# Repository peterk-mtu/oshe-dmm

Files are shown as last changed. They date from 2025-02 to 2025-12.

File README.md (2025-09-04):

# oshe-dmm
open source hardware enterprise digital multimeter project

# Photo of our proposed design
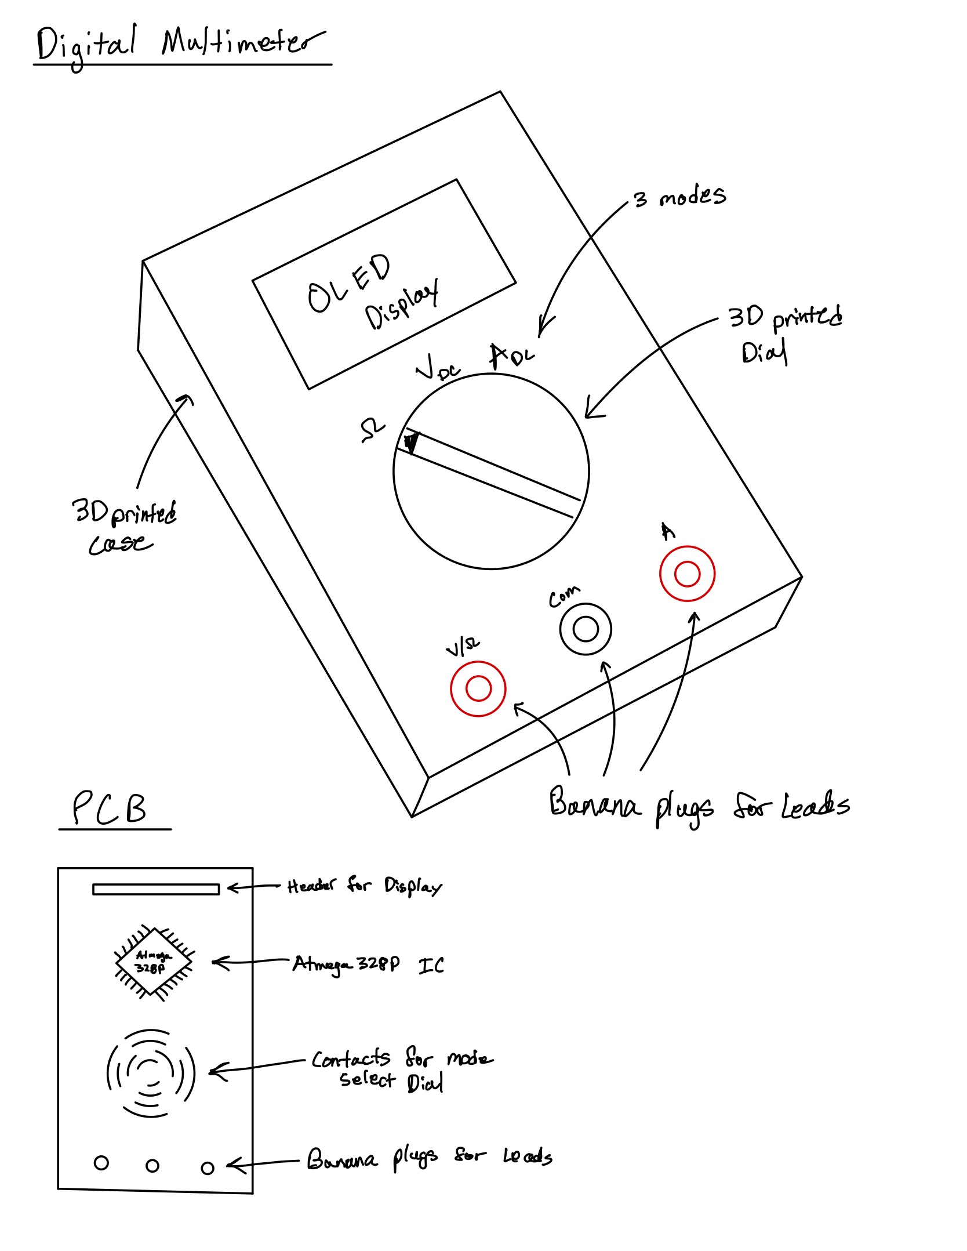
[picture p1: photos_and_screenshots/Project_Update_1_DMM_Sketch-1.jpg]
A rough sketch of our proposed design


# Screenshot of the start to our PCB design
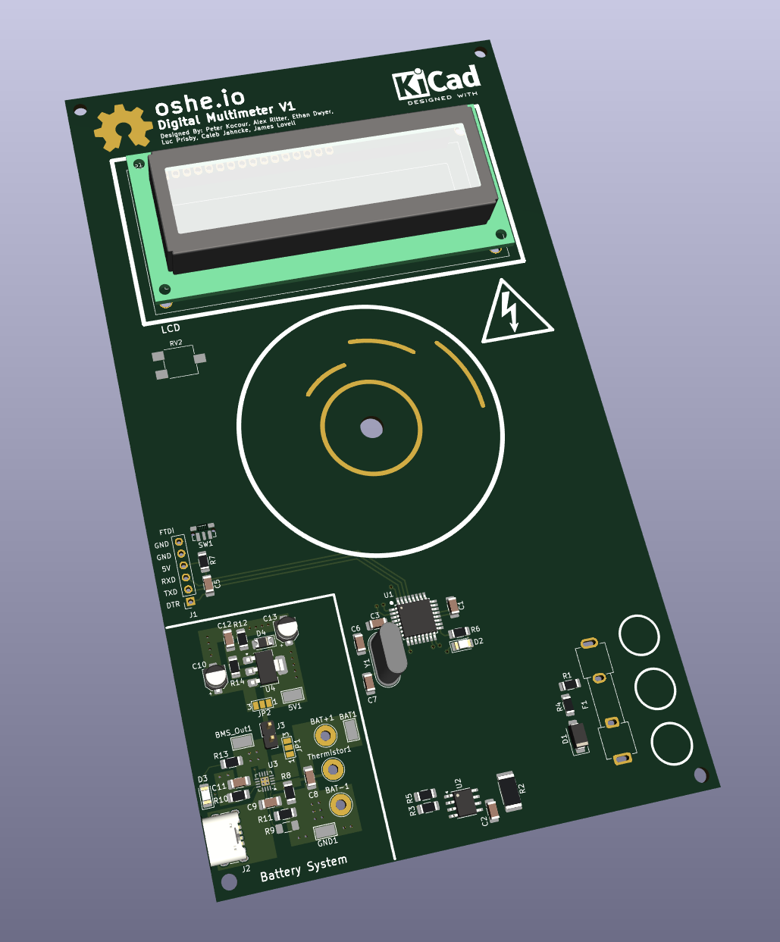
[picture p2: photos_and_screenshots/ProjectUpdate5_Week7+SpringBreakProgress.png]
A screenshot of our inital PCB work


# Screenshot of the Final PCB design
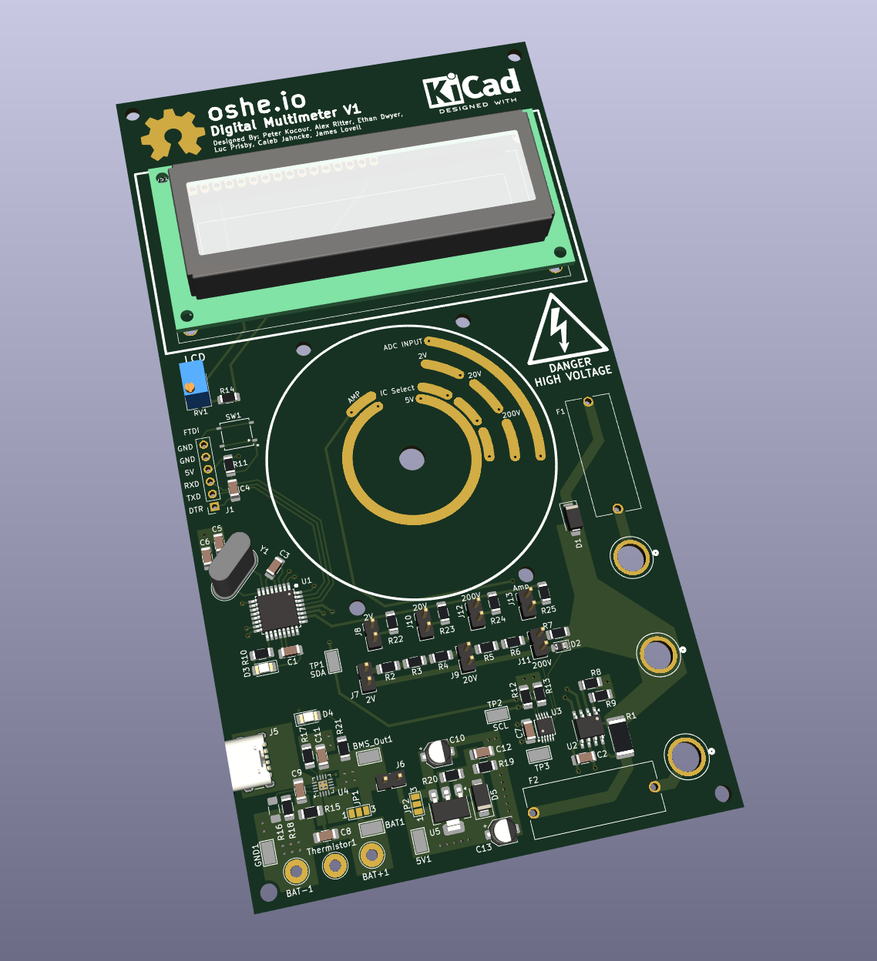
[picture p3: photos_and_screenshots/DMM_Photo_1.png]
A screenshot of our Final PCB Design


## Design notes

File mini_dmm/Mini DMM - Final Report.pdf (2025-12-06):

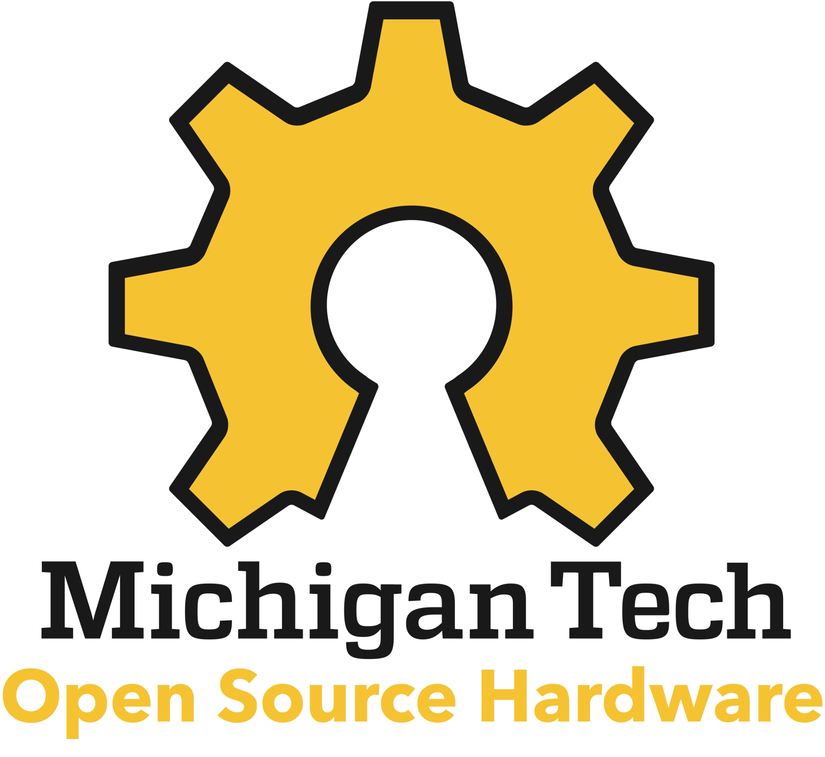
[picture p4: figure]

# Mini Digital Multimeter Project

## Fall 2025 Report

### Project Team: Peter Kocour Ian Ranstadler Nathan Campbell

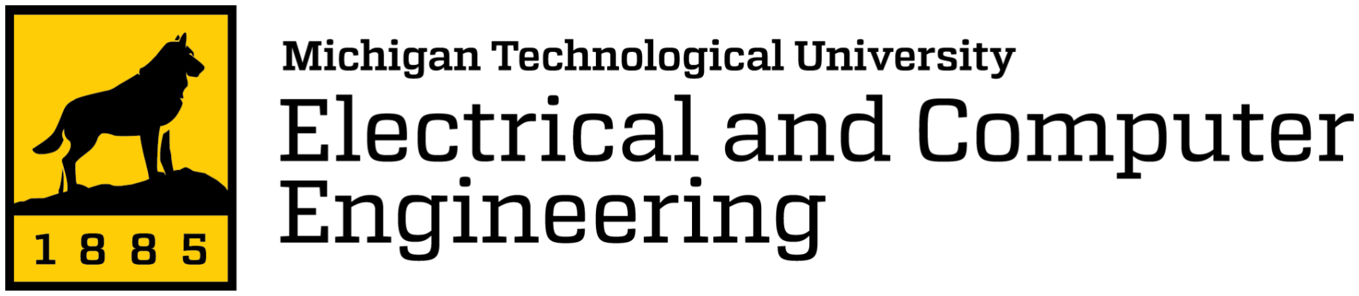
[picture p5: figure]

Mini Digital Multimeter Project Report | Fall 2025

### Table of Contents

### 1. Executive Summary

The Mini Digital Multimeter Project presents a compact measurement device, about the size of a credit card, which is capable of capturing DC voltage measurements of up to 30 volts and DC current measurements of up to 1 amp. It’s designed with affordability and mass production in mind, maintaining a bill of materials cost of roughly $10 per unit at a scale of 100 units.

Core Technology
The Digital Multimeter utilizes the ATmega328P microcontroller, common on arduino platforms, supplemented by a four circuit op-amp, a charge pump, a display driver, and a 4 digit display. The four circuit op-amp provides a buffer for the inputs of the ATmega internal ADC for voltage measurements and provides amplification for the current measurements. The op-amp is provided with both a positive 3.3 volt supply via the battery and a negative 3.3 volt supply via the charge pump. The measured voltages and currents are then displayed through the display driver and onto the 4 digit display.

Innovations
Several key innovations were integrated in the mini digital multimeter, from a unique display and display driver combo to a single op-amp floating shunt resistor circuit measurement circuit, which pushed the limits of accuracy while maintaining a low overall bill of material cost. The display driver and 4 digit display proved to be the most challenging, requiring a deep dive into the display driver datasheet and the C++ code to determine how to get the correct segments to turn on and off on the display based on a collected measurement. Another innovation was the addition of a charge pump to provide the required negative 3.3 volts for the supply rail of the op-amp with the addition of a few capacitors. For current measurement, it was discovered that the change in voltage drop across a small shunt resistor was too small for the internal ADC to see, thus requiring some sort of amplification to make it easier to identify changes in voltages and thus changes in currents.

Challenges and Solutions
Our greatest challenge with the project stemmed from the display and display driver IC. One critical part of the project was keeping costs low. The display on the previous design was not only physically bulky but pretty pricey for our goal of a small, low cost device. Moving away from the LCD to a cheaper alternative proved limiting and challenging. Most displays were not cheap, often in the range of $2 to $5, much more than we would like to spend. As a solution, we found the LCD-S401M16KR by Lumex which was at most $1.67 at low quantities, but more importantly, the price dropped to $0.8991 when ordering a quantity of 100. While this initially solved our first problem, it created a second, driving the display that wants an AC voltage signal. One potential solution was using a PWM signal from the microcontroller pins to see if that would be enough to turn on and off the display. During testing this solution almost worked, however, it took up all of the GPIO pins, saving nothing for the rest of the devices, like LEDs, switches, etc, we needed to use. This ultimately led to the use of the BU91796FS-ME2 display driver IC. This device could be communicated with over I2C, would handle all of the AC signal,

1/4 duty, 1/3 bias, requirements of the display and only cost $1.1022, putting our total cost at just around $2 being one of the cheapest options. Pawning off the control of the display to this driver frees up many of the GPIO pins on the microcontroller while also handling all of the challenges with driving the display. That being said, this solution still introduced another problem, finding the right I2C commands to turn on and off the current segments on the display when we need or want to. Programming the correct commands was a challenge that didn’t get solved at the end of the semester. While some of the segments turn on when commanded displaying the numbers 1, 4, 0, 5, and a few others correctly, not every segment turns on when needed, preventing every number from being displayed correctly. With some more time spent in the datasheet for the display driver and the I2C commands, the correct commands could eventually be determined.

Impact
The Open Source MINI Digital Multimeter offers a hands-on give-away item to future MTU students or others interested in electronics. This device will give its users a hands-on education of electronics, promoting technical development at a fraction of the cost of a commercial multimeter. By open-sourcing hardware and software, this project encourages students, makers, and educators to innovate, customize, and better understand electronics and electrical tools.

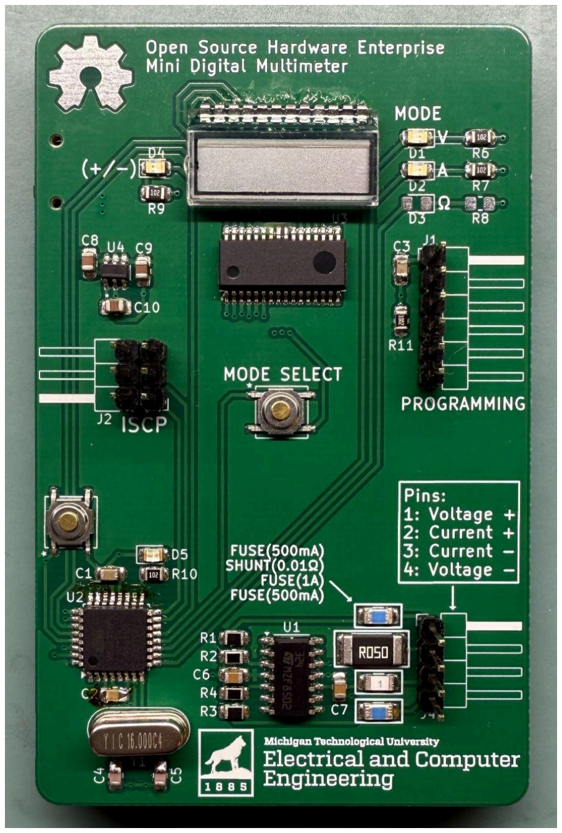
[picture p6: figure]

Figure 1: Mini DMM Version 1 Product Image

### 2. Project Description

The Mini Digital Multimeter Project presents a compact measurement device, about the size of a credit card, which is capable of capturing DC voltage measurements of up to 30 volts, DC current measurements of up to 1 amp, and resistance measurements up to 100,000 ohms. Designed with affordability and mass production in mind, the device will maintain a bill of materials cost of roughly $10 per unit at a scale of 100 units and prioritize surface mount components while minimizing through hole components where possible. Switching between measurement modes will be easy and intuitive, with a clear mode selection button and indicators to guide users to their desired measurement type. This device will also employ numerous safety features such as fuses, graphical warnings and an enclosure to protect users and ensure safe operation.

### 3. Methodology

### 3.1 Voltage Measurement

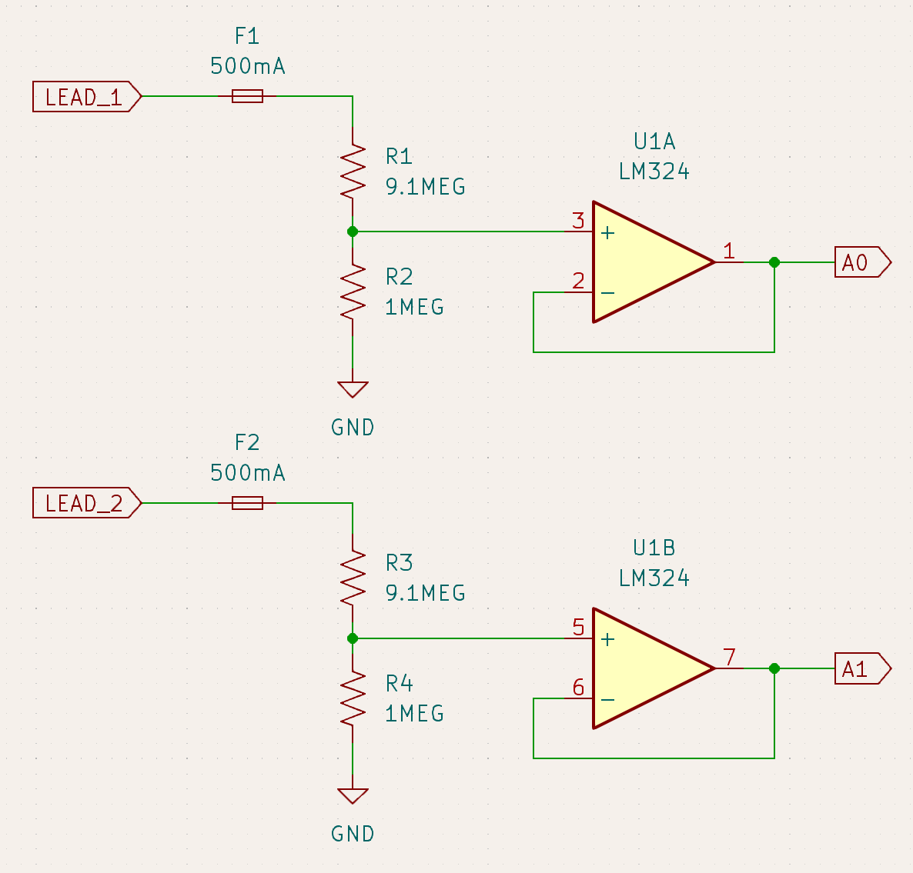
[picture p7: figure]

Figure 2: Voltage measurement schematic

Voltage measurement was one of the most important design aspects of our project. When laid out in our project specifications, we ultimately decided that we wanted the voltage to be measured in DC between ± 30 V and we wanted that measured value to be within ±10% of any commercially available device that it was put up against. Our final design for voltage measurement can be seen above in Figure 2, which was composed of two separate circuits. Initially, we considered using a processor that was capable of taking differential measurements as we thought this would be the way that our voltage measurements were taken. However, we found a different method where that differential measurement requirement was not needed. This allowed us to switch our processor to the ATmega328p which was cheaper, programmable in the Arduino IDE, and had more open pins which was helpful as we ran out while using the STM32F303. The circuit itself makes use of two separate voltage dividers with a known ratio, 10.1:1. Using this ratio and some simple math, we were able to take two different voltage measurements between our probes and subtract one from the other. The voltage divider also allowed us to get our input voltage into our Op-amps to be ±3V, as we only had a ±3V supply rail available to run our components. The buffer op-amps added before the ADC input are meant to prevent input impedance from our test leads, and thus making our measurements more accurate. For safety reasons, we also added 500 mA fuses just after leads to prevent the ADC from burning up should an unexpected current be placed through the leads. These components were ultimately decided to be simple SMD components due to their price, though they can be replaced by the right person.

### 3.2 Current Measurement

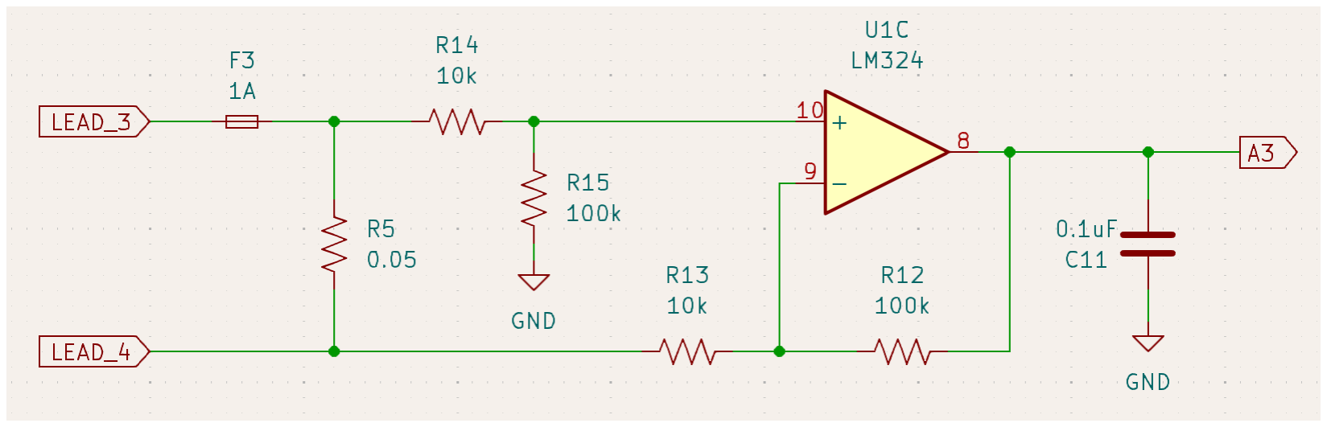
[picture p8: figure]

Figure 3: Current Measurement schematic

Current measurement was another critical aspect of our design. During the research phase of the project, it was identified that we want the device to be capable of measuring up to 1 amp of DC current. Due to cost reasons, a dedicated current measurement IC as used in a previous semester of the project, could not be used in this design. Instead, an op-amp current shunt resistor approach was taken which significantly reduces the cost of the current measurement circuit. During the design phase, initially the current was measured using a 1 Ohm shunt resistor, which produced a relatively large voltage drop across the load. This simplified measurement, higher resistance produces a higher measurable voltage, but it also introduces significant power dissipation (P = I

2 * R ), especially at higher currents. We were planning on the maximum measured current being 1 Amp, meaning we would have 1 Watt of Power going across it. During the Critical Design Review (CDR), we determined that it would be best to use a smaller resistor to ensure safe usage. The wattage rating we would need for the 1 Ohm resistor would be around 2 Watts, considering you want it to be at least double the expected load, in comparison to .1 Watts for the .05 Ohm resistor. Considering the budget, the .05 Ohm resistor made the most sense.

When taking current measurements, we used a shunt resistor and op-amp configuration based on the circuit described at labprojectsbd.com. (https://labprojectsbd.com/2020/05/09/dc-current-measurement-using-shunt-resistor-and-op-amp-circuit/) As mentioned above, the shunt resistor we chose, .05 Ohms, produces a small voltage in the mV range. In order to reach a value more easily measured, it was fed into an LM324, which amplified the signal before sending it to an ADC input (A3). After the amplified values were fed into the ADC inputs, they reached the microcontroller, the ATMEGA328P-AU. The current is then calculated. First, the .05 Ohm shunt resistor converts the current into a voltage drop according to Ohm’s Law, for example, a 1 Amp current would produce around 50 mV of voltage. That drop is then amplified by the LM324 op-amps before feeding into the ADC (A3) of the ATMEGA328P-AU, where the current is calculated using the formula below:

I = | [1] Vout
Rsℎunt * Gain

Where Vout is the amplified voltage, Gain is the gain of the op-amp, and Rshunt is the resistance of the shunt resistor. In the system, there is a 1 Amp fuse that helps to ensure that currents above what can be handled don’t destroy the entire system. When choosing the components for the current measurement, the parts were picked out to be relatively easy to hand-solder.

### 3.3 Resistance Measurement

An initial idle goal we considered was integrating resistance measurement into our design. We considered 100000 ohms to be a plausible max if we were to get resistance measurement to work properly. Initial research into the subject gave examples of ohmmeters that only had the ability to measure in milliohms. Going further, we consulted the larger Digital Multimeter project as they had a method to measure resistance in the megaohm range. They in turn had used a design they found online repurposed for their needs [12]. This gave us a good starting point, but more needed to be done if we wanted to use this same design in our own project. Several hours were devoted to figuring out how each part of the ohmmeter worked and how we could translate those components into surface mount and making it small enough to fit within our size constraints outlined in 3.5 PCB Design. After working at it for a while, it was realized that resistance measurement required more time, energy, and research than we were able to provide so the idea was ultimately scrapped.

### 3.4 Display and Display Driver

Unlike last semester, space and cost were major factors in our project design. To accomplish this, a new display needed to be selected instead of using the previous 16x2 character LCD from last semester. During our research, we found the LCD-S401M16KR by Lumex to be a potential solution for our needs. Its single unit cost was $1.67 with the price dropping to $0.8991 when ordering a quantity of 100. One characteristic that needed to be considered with selecting this display was how to drive it. Unique to these tiny displays, they want to be driven by an AC, 1/4 duty, 1/3 bias signal while simultaneously switching an internal mux to control what segments will turn on and off. Originally, this was attempted through just using the GPIO pins on the microcontroller, while this did turn certain segments on and off, it used all of the GPIO pins available and didn’t fully work the way we had intended. This ultimately led to the use of the BU91796FS-ME2 display driver IC. This device could be communicated with over I2C, would handle all of the AC signal, 1/4 duty, 1/3 bias, requirements of the display and only cost $1.1022, putting our total cost at just around $2, one of the cheapest options compared to other displays. Pawning off the control of the display to this driver frees up many of the GPIO pins on the microcontroller while also handling all of the specific characteristics with driving the display. While this solution led to more progress than using just the GPIO pins on the microcontroller, only a few numbers were able to be displayed by the end of the semester. With a bit more time and effort, the correct I2C commands could be determined to properly display all possible numbers correctly on the display.

### 3.4 Programming

The firmware for this device was written in C++ through the Arduino IDE. The ATmega328 processor used in this device is the same processor used for the Arduino Uno’s, combine this with the Arduino IDE and there are many libraries available that can be used in the firmware for the device. Additionally, many artificial intelligence (AIs) have been trained with C++ and Arduino programs, which improves the chances that using an AI to assist with programming will lead to a functional result. That being said, AI was used in an attempt to generate many of the I2C commands for the display driver, while it greatly helped finding a majority of the commands, there were a few commands/segments that were not located and would require more troubleshooting and review of the datasheet to correct. Aside from this, the program functions flawlessly and can be downloaded from our GitHub and programmed onto the device. The device will require a bootloader prior to programming from the Arduino IDE, see our references on flashing the bootloader to the ATmega328 for more thorough instructions and troubleshooting steps. Once the bootloader has been flashed, the Arduino IDE will now recognize the device and the firmware can be uploaded using a USB to UART adapter or a second Arduino. Plans are in place for a future addition of a USB to UART IC being placed on the board along with a USB port for direct programming of the device.

### 3.5 PCB Design

After completing each subsection of the schematic, we moved onto the PCB design and layout. There were many versions of the PCB created with various dimensions, component layouts, graphics, etc. in an attempt to get everything to fit onto the board in an intuitive way. Eventually, each subsection of the schematic was laid out separately from the board to ensure each section had its most optimal layout based on the components datasheets and where the user might interact with the device. After which, all subsections were combined into the remaining space on the board and any components that were interfering with one another were relocated. One of the primary ideas that we kept in mind when designing the board layout was keeping all components on the top side of the board, aside from the battery holder and power switch, for this first initial prototype, to make debugging and assembly much easier. After quite a lot of layout tweaking, we reached our final design for our initial prototype shown in Figure 4.

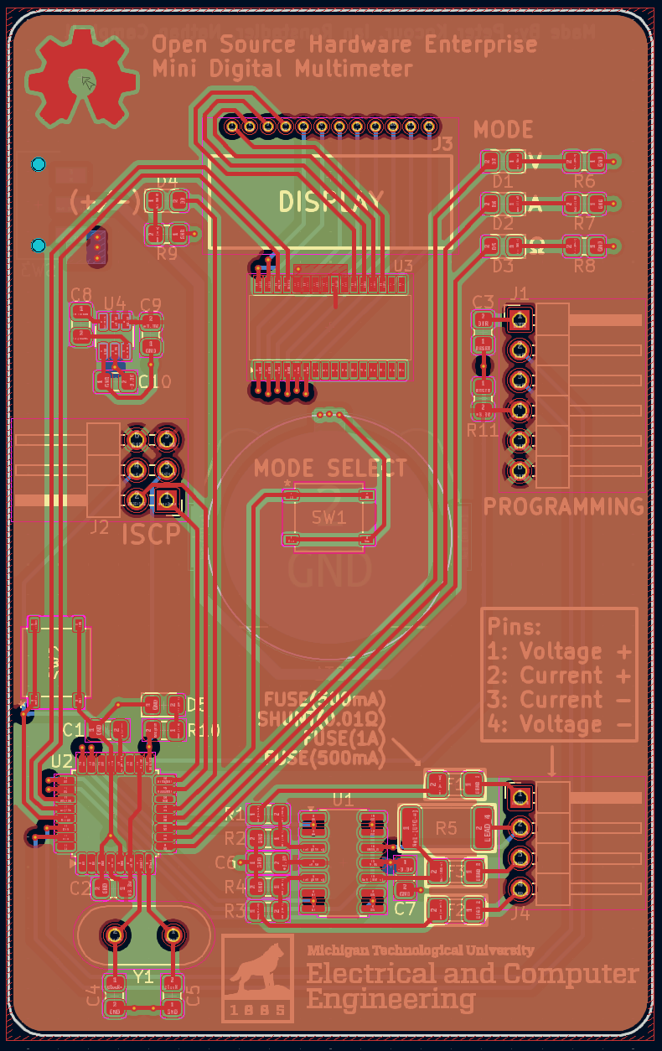
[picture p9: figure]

Figure 4: Initial Prototype PCB Design

### 3.6 Enclosure

The enclosure was designed to allow for easy and quick 3D printing and assembly. It's composed of two different halves, the case and the lid, and assembled using four small phillips head screws. It is printed using PLA filament and is a simple shell to house the device and add some protection to both the device and the user. The working prototype can be seen below in Figure 5, with plans to refine it for future production.

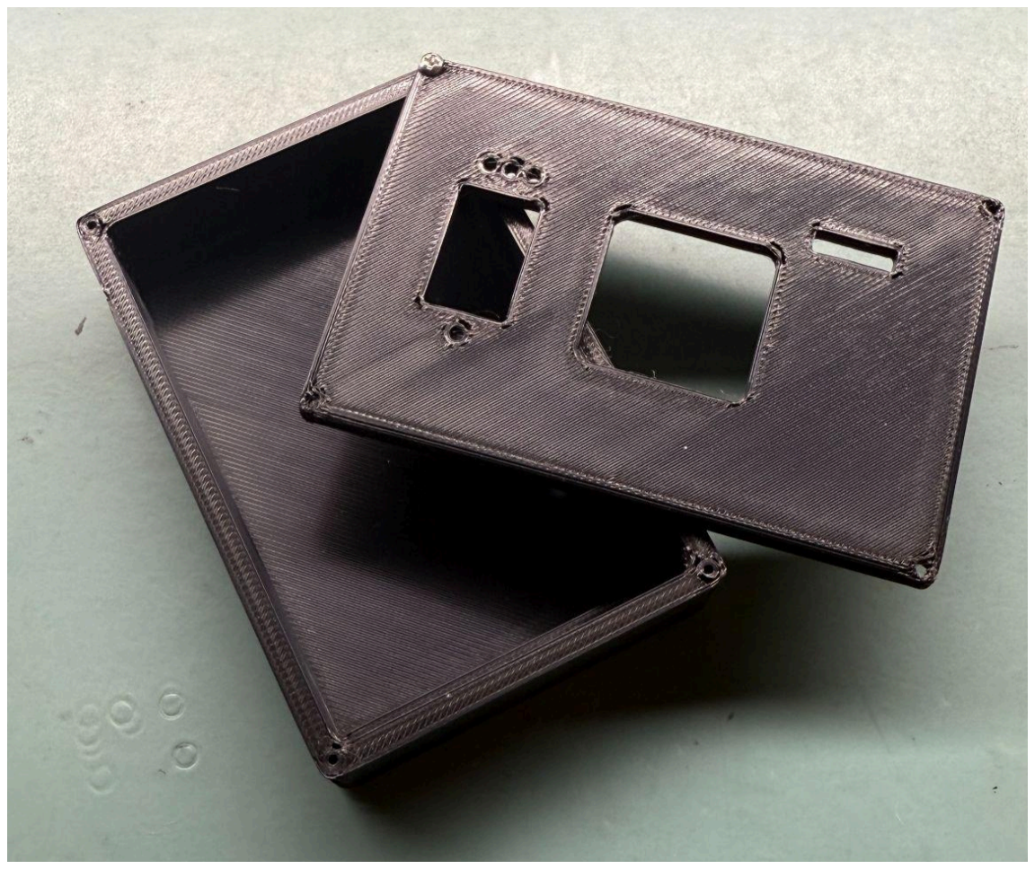
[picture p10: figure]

Figure 5: Initial Prototype 3D Printed Case

### 4. Bill of Materials (BOM)

Table 1: Bill of Materials

Designator | QTY | Component Value | Part Number | Cost
U2 | 1 | MCU | ATMEGA328P-AU | $2.66
U1 | 1 | Op-Amp | LM324DT | $0.25
U4 | 1 | Charge Pump | LM2664M6X/NOPB | $0.92
J3 | 1 | Display | LCD-S401M16KR | $1.67
U3 | 1 | Display Driver | BU91796FS-ME2 | $1.85
R5 | 1 | 0.01 | PA0805FRF870R01L | $0.70
R1,R3 | 2 | 9.1 MEG | CRCW08059M10FKEA | $0.10
R2,R4 | 2 | 1 MEG | CRCW08051M00FKEA | $0.10
R6, R7, R8, R9 | 5 | 1k | CRCW08051K00JNEAC | $0.10
R11 | 1 | 10k | CRCW080510K0FKEAC | $0.10
F3 | 1 | 1 A | C1F 1 | $0.34
F1,F2 | 2 | 500 mA | C1Q 500 | $0.37
D1,D2,D3,D4,D5 | 5 | Green LED | LTST-C170GKT | $0.10
C1,C2,C3 | 3 | 0.1uF | C0805C104K5RACTU | $0.08
C6,C7 | 2 | 1uF | CL21B105KBFNNNE | $0.08
C8,C9,C10 | 3 | 10uF | CL21A106KOQNNNE | $0.08
C4,C5 | 2 | 22pF | CL21C220JBANFNC | $0.10
Y1 | 1 | 16MHz | 16M20P2/49US | $0.15
SW1,SW2 | 2 | Switch | PTS526SK15SMTR2 LFS | $0.14
SW3 | 1 | Switch | JS102011SAQN | $0.76
J1,J2,J4 | 1 | Pin Header | 61301611121 | $0.87
BT1 | 1 | Holder | 3034 | $0.40
BT1 | 1 | Battery | CR2032 | $0.33
Screws | 4 | Screws | #2 x 1/4" Pan Head Sheet Metal Screws | $0.28
PCB | 1 | JLCPCB | JLCPCB | $2.00
| | | TOTAL | $14.53

### 5. Tools Used

Table 2: Software Used

Name | Description | Price | Link
GitHub Desktop | Used to share updates and versions. | Free | GitHub.com
KiCAD | Software utilized to design PCB and electrical schematics | Free | KiCAD.com
OnShape | Used to design the enclosure and dial to controls the PCB | Free | OnShape.com
PrusaSlicer | Software used to slice the OnShape file to prepare to be 3D printed. | Free | prusa3d.com (https://www.prusa3d.com/page/prusaslicer_424/)
Total Cost | | Free

Table 3: Hardware Used

Name | Part Number | Description | Price | Link
3D-Printer | Original Prusa MINI+ | Used to print enclosure for multimeter | $459 | prusa3d.com (https://www.prusa3d.com/product/original-prusa-mini-semi-assembled-3d-printer-4/)
Soldering Iron | Hakko FX888DX | Used for through hole components and PCB corrections | $118 | Amazon.com (https://www.amazon.com/Hakko-FX888DX-010BY-Digital-Soldering-Station/dp/B0D4DJW54S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)
Solder Wire | Enersystec | | $19.99 | Amazon.com (https://www.amazon.com/Electrical-Electronics-Soldering-Connector-0-032in/dp/B08L6K2DSG)
Multimeter | Fluke | The Multimeter was from the OSHE lab to test components, debug test circuits, and accuracy against our Multimeter
Tweezers | Electronics | Tweezers used to place | $5.99 | Amazon.com (https://www.amazon.com/kaverme-Anti-Static-Electronics-Laboratory-Jewelry-Making/dp/B0BNNGC3Q2)

| Tweezers | surface mounted components onto the PCB
Pneumatic Solder Dispenser | METCAL DX-250 | | $587.00 | Metcal.com (https://store.metcal.com/en-us/shop/fluid-dispensing/dispensers/DX-250)
Solder Paste | Chip Quik NC191LTA35 | Solder paste used to mount surface mount components to the PCB. | $17.95 | Digikey.com (https://www.digikey.com/en/products/detail/chip-quik-inc/NC191LTA35/13531409)
Reflow Oven | Manncorp MC301 (Legacy) | The reflow oven was used to melt the solder paste to solder all surface mount components to the circuit board. | Unknown | Unknown
Total Cost | | | $ May Vary

### 6. Assembly Instructions

### 6.1 PCB Assembly

- Step 1: If using solder paste, apply paste to each SMD pad on the PCB
- Step 2: Place SMD components onto the PCB using a pick and place machine or by hand using tweezers following the reference designators.
- Step 3: Place the board into the reflow oven with the temp probe on top and run the reflow profile for the specific paste you are using.
- Step 4: Verify good solder joints on components, then move onto through hole components in the next step.
- Step 5: Place the through hole components onto the top side of the board, flip over the board and use solder wire and a soldering iron to solder each through hole lead. Refer to the board assembly references section below for hand soldering techniques.

- Step 6: Once all through hole components are placed, cut the excess leads off using a wire cutter.
- Board Assembly References:
- SMD Reflowing: https://www.youtube.com/watch?v=yZqrrq6VpKY
- Hand Soldering Techniques: https://www.youtube.com/watch?v=6rmErwU5E-k
- Hand Soldering Techniques: https://www.youtube.com/watch?v=vAx89WhpZ3k
- Identifying Bad Solder Joints: https://www.youtube.com/watch?v=qUzoG6O5JI0

### 6.2 Enclosure Replication

- Step 1: Download the STL files from GitHub and import them into your preferred slicing software.
- Step 2: Adjust print settings such as infill, layer height, etc for the specific speed and/or quality you are looking for out of the part. Usually the standard settings will be fine for these parts.
- Step 3: Print the lid and base for the device.
- Step 4: Place the PCB inside the case. You can use some double sided tape to hold it down if necessary.
- Step 5: Screw the lid of the case using four phillips screws.

### 7. Characterization Data

Table 4: Characterization Data (OSHE DMM vs Fluke)

Voltage | Current
OSHE MINI DMM | Klein Tools | OSHE MINI DMM | Klein Tools
4.97 V | 4.98 V | 00.00 mA | 00.00 mA
9.93 V | 10.00 V | 7.54 mA | 8.11 mA
14.95 V | 14.96 V | 15.13 mA | 15.79 mA
20.05 V | 20.03 V | 28.32 mA | 29.11 mA
24.96 V | 24.96 V
29.68 V | 29.55 V

Characterization Testing Notes:

- The voltage measurement test circuit consisted of the mini digital multimeter being connected in parallel with a 30 volt DC power supply and the Klein Tools multimeter.
- The current measurement circuit was three 1k resistors in series which started at nothing being connected, then four resistors, then three resistors, then two resistors, and finally just one resistor.

### 8. Sponsors/Acknowledgements

- This project is currently self sponsored by the MTU Open Source Hardware Enterprise.

### 9. References

[1] Github Repository: https://github.com/peterk-mtu/oshe-dmm
[2] “Digital multimeter (DMM) design resources | TI.com,” Ti.com, 2025.
https://www.ti.com/solution/digital-multimeter-dmm?variantid=20220#block-diagram (accessed Apr. 24, 2025).
[3] “Arduino as ISP and Arduino Bootloaders,” Arduino.cc, Jan. 20, 2018. https://docs.arduino.cc/built-in-examples/arduino-isp/ArduinoISP/
[4] Electronoobs, “Handheld Multimeter,” electronoobs.com, Dec. 01, 2024. https://electronoobs.com/eng_arduino_tut194.php#google_vignette
[5] IPC, IPC-2221: Generic Standard on Printed Board Design, Northbrook, IL: Institute for Interconnecting and Packaging Electronic Circuits, Feb. 1998. [Online]. Available: https://www-eng.lbl.gov/~shuman/NEXT/CURRENT_DESIGN/TP/MATERIALS/IPC_2221.p df (https://www-eng.lbl.gov/~shuman/NEXT/CURRENT_DESIGN/TP/MATERIALS/IPC_2221.pdf)
[6] M. Das, “DC Current measurement using Shunt resistor and Op-Amp Circuit” Lab Projects BD, Sep. 05, 2020. https://labprojectsbd.com/2020/05/09/dc-current-measurement-using-shunt-resistor-and-op-amp-circuit/ (https://labprojectsbd.com/2020/05/09/dc-current-measurement-using-shunt-resistor-and-op-amp-circuit/)
[7] M. R. Thakur and A. Y. says:, “DC current measurement using shunt resistor,” Circuits4you.com,
https://circuits4you.com/2016/05/13/dc-current-measurement-arduino/#google_vignet te (https://circuits4you.com/2016/05/13/dc-current-measurement-arduino/#google_vignette) (accessed Dec. 5, 2025).
[8] M. James, “Build your own ohmmeter!,” Programming Electronics Academy, Sep. 08, 2021. https://www.programmingelectronics.com/ohmmeter/ (accessed Dec. 04, 2025).

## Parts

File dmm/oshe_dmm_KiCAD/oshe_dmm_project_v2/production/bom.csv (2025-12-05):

Designator | Footprint | Quantity | Value | LCSC Part #
5V1, BAT1, GND1 | TestPoint_Keystone_5019_Minature | 3 | TestPoint
BAT+1, BAT-1, THERMISTOR1 | TestPoint_THTPad_D4.0mm_Drill2.0mm | 3 | Pad
C1, C2, C3, C4, C7 | 1206 | 5 | 0.1uF
C10, C11, C13, C14, C18 | CP_Elec_4x4.5 | 5 | 1uF
C12, C16, C17, C8 | 1206 | 4 | 10uF
C15 | CAPC3216X190N | 1 | 100uF
C5, C6 | 1206 | 2 | 22pF
C9 | CP_Radial_D6.3mm_P2.50mm | 1 | 220u
D1 | D_SMA | 1 | SMAJ200CA
D2 | 0805 | 1 | VS4V8BU1ART7R
D3 | 1206 | 1 | Green
D4, D7 | D_SMA | 2 | SMAJ200A
D5 | D_SMA | 1 | S1B
DS1 | WC1602A | 1 | WC1602A
F1 | FUSE_4628 | 1 | 500mA
F2 | FUSE_4628 | 1 | 5A
J1 | PinSocket_1x06_P2.54mm_Vertical | 1 | FTDI Basic
J10, J9 | PinHeader_1x02_P2.54mm_Vertical | 2 | Voltage Range 2
J11, J12 | PinHeader_1x02_P2.54mm_Vertical | 2 | Voltage Range 3
J13 | PinHeader_1x02_P2.54mm_Vertical | 1 | DC Current Indication
J14 | PinHeader_1x02_P2.54mm_Vertical | 1 | Continuity
J16 | PinHeader_1x02_P2.54mm_Vertical | 1 | AC Voltage Range 2
J18 | PinHeader_1x02_P2.54mm_Vertical | 1 | AC Voltage Range 3
J2 | CONN_575-8_KEY | 1 | Voltage
J20 | PinHeader_1x02_P2.54mm_Vertical | 1 | AC Voltage Range 1
J21 | PinHeader_1x02_P2.54mm_Vertical | 1 | AC Current Indication
J22 | SAMESKY_MJ-3536N | 1 | MJ-3536N
J3 | CONN_575-8_KEY | 1 | GND
J4 | CONN_575-8_KEY | 1 | Current
J5 | PinHeader_1x02_P2.54mm_Vertical | 1 | Resistance Meas
J6 | PinHeader_1x02_P2.54mm_Vertical | 1 | ON/OFF
J7, J8 | PinHeader_1x02_P2.54mm_Vertical | 2 | Voltage Range 1
R1 | 2512 | 1 | 0.05
R10, R14, R20 | 1206 | 3 | 390
R11, R12, R13, R15, R21, R7 | 1206 | 6 | 10k
R16 | 1206 | 1 | 49.5
R17 | 1206 | 1 | 100
R18, R8 | 1206 | 2 | 1k
R19, R24 | 1206 | 2 | 1.2k
R2 | 1206 | 1 | 470k
R22 | 1206 | 1 | 180
R23 | 1206 | 1 | 680
R25, R34, R39, R9 | 1206 | 4 | R?
R26, R31 | 1206 | 2 | 1M
R3 | 1206 | 1 | 330k
R30, R4 | 1206 | 2 | 100k
R32 | 1206 | 1 | 4.99M
R33 | 1206 | 1 | 10M
R36 | 1206 | 1 | 2.4k
R37 | 1206 | 1 | 3k
R38 | 1206 | 1 | 1.8k
R5 | 1206 | 1 | 47k
R6 | 1206 | 1 | 43k
RV1 | Potentiometer_Bourns_3266Y_Vertical | 1 | 10k - Pot
SW1 | SMT_FS | 1 | PTS526 SK15 SMTR2 LFS
U1 | TQFP-32_7x7mm_P0.8mm | 1 | ATmega328P-A
U2 | PDIP-8_N | 1 | AD736
U3, U8 | MODULE_ZC261500 | 2 | ADS1115IDGS
U4 | DIP794W47P254L1943H457Q16 | 1 | MAX4617CPE
U5 | SOT-223-3_TabPin2 | 1 | LM317_SOT-223
U7 | SOT-23-5 | 1 | TPS60400DBV
Y1 | Crystal_HC49-U_Vertical | 1 | 16MHz

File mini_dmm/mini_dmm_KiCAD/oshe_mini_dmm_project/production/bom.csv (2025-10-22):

Designator | Footprint | Quantity | Value | LCSC Part #
BT1 | BatteryHolder_Keystone_3034_1x20mm | 1 | Battery
C1, C2, C3 | 0805 | 3 | 0.1uF
C10, C8, C9 | 0805 | 3 | 10uF
C4, C5 | 0805 | 2 | 22pF
C6, C7 | 0805 | 2 | 1uF
D1 | 0805 | 1 | VOLTAGE
D2 | 0805 | 1 | CURRENT
D3 | 0805 | 1 | RESISTANCE
D4 | 0805 | 1 | NEGATIVE
D5 | 0805 | 1 | Green
F1, F2 | 1206 | 2 | 500mA
F3 | 1206 | 1 | 1A
J1 | PinHeader_1x06_P2.54mm_Horizontal | 1 | FTDI Basic
J2 | PinHeader_2x03_P2.54mm_Horizontal | 1 | ICSP
J3 | LCD-S401M16KR-81359 | 1 | DISPLAY
J4 | PinHeader_1x04_P2.54mm_Horizontal | 1 | TEST LEAD CONNECTIONS
R1, R3 | 0805 | 2 | 9.1MEG
R10 | 0805 | 1 | 390
R11 | 0805 | 1 | 10k
R2, R4 | 0805 | 2 | 1MEG
R5 | 2512 | 1 | 0.05
R6, R7, R8, R9 | 0805 | 4 | 1k
SW1, SW2 | SMT_FS | 2 | PTS526 SK15 SMTR2 LFS
SW3 | SW_JS102011SAQN | 1 | SW_DPDT_x2
U1 | SOIC-14_3.9x8.7mm_P1.27mm | 1 | LM324
U2 | TQFP-32_7x7mm_P0.8mm | 1 | ATmega328P-A
U3 | SSOP-A32 | 1 | BU91796FS-ME2
U4 | SOT95P280X145-6N | 1 | LM2664M6
Y1 | Crystal_HC49-U_Vertical | 1 | 16MHz

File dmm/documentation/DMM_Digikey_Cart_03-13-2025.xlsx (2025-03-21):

Index | Quantity | Part Number | Manufacturer Part Number | Description | Customer Reference | Available | Backorder | Unit Price | Extended Price USD
1 | 14 | 36-5019CT-ND | 5019 | PC TEST POINT MINIATURE |  | 14 | 0 | 0.267 | 3.74
2 | 10 | 732-7867-1-ND | 885012008011 | CAP CER 22PF 16V C0G/NP0 1206 |  | 10 | 0 | 0.093 | 0.93
3 | 10 | 1276-1804-1-ND | CL31B106KAHNNNE | CAP CER 10UF 25V X7R 1206 |  | 10 | 0 | 0.089 | 0.89
4 | 6 | 732-8541-1-ND | 865060640001 | CAP ALUM 1UF 20% 50V SMD |  | 6 | 0 | 0.15 | 0.90
5 | 4 | SMAJ200CALFCT-ND | SMAJ200CA | TVS DIODE 200VWM 324VC DO214AC |  | 4 | 0 | 0.36 | 1.44
6 | 4 | 846-VS4V8BU1ART7RCT-ND | VS4V8BU1ART7R | TVS DIODE 4.8VWM 11VC SMD2012 |  | 4 | 0 | 0.58 | 2.32
7 | 4 | S1BFSCT-ND | S1B | DIODE GEN PURP 100V 1A DO214AC |  | 4 | 0 | 0.24 | 0.96
8 | 6 | 36-4628-ND | 4628 | FUSE HLDR CARTRIDGE 250V 5A PCB |  | 6 | 0 | 0.81 | 4.86
9 | 5 | 486-1217-ND | 0034.3114 | FUSE GLASS 500MA 250VAC 5X20MM |  | 5 | 0 | 0.63 | 3.15
10 | 5 | F2395-ND | 0217005.HXP | FUSE GLASS 5A 250VAC 5X20MM |  | 5 | 0 | 0.382 | 1.91
11 | 10 | 36-575-8-ND | 575-8 | CONN BANANA JACK SOLDER |  | 10 | 0 | 0.886 | 8.86
12 | 3 | 2073-USB4125-GF-A-0190CT-ND | USB4125-GF-A-0190 | CONN RCPT TYPE C 6P SMD RA |  | 3 | 0 | 0.59 | 1.77
13 | 4 | CRA2512-FZ-R050ELFCT-ND | CRA2512-FZ-R050ELF | RES 0.05 OHM 1% 3W 2512 |  | 4 | 0 | 0.55 | 2.20
14 | 10 | 311-470KFRCT-ND | RC1206FR-07470KL | RES 470K OHM 1% 1/4W 1206 |  | 10 | 0 | 0.016 | 0.16
15 | 10 | RMCF1206FT330KCT-ND | RMCF1206FT330K | RES 330K OHM 1% 1/4W 1206 |  | 10 | 0 | 0.029 | 0.29
16 | 10 | 311-100KFRCT-ND | RC1206FR-07100KL | RES 100K OHM 1% 1/4W 1206 |  | 10 | 0 | 0.017 | 0.17
17 | 10 | 311-43.0KFRCT-ND | RC1206FR-0743KL | RES 43K OHM 1% 1/4W 1206 |  | 10 | 0 | 0.018 | 0.18
18 | 10 | RMCF1206FT390RCT-ND | RMCF1206FT390R | RES 390 OHM 1% 1/4W 1206 |  | 10 | 0 | 0.029 | 0.29
19 | 10 | RMCF1206JG1K50CT-ND | RMCF1206JG1K50 | RES 1.5K OHM 5% 1/4W 1206 |  | 10 | 0 | 0.026 | 0.26
20 | 10 | 738-RMCF1206FT1K78CT-ND | RMCF1206FT1K78 | RES 1.78K OHM 1% 1/4W 1206 |  | 10 | 0 | 0.029 | 0.29
21 | 10 | 738-RMCF1206FT1K20CT-ND | RMCF1206FT1K20 | RES 1.2K OHM 1% 1/4W 1206 |  | 10 | 0 | 0.029 | 0.29
22 | 10 | RMCF1206FT3K30CT-ND | RMCF1206FT3K30 | RES 3.3K OHM 1% 1/4W 1206 |  | 10 | 0 | 0.029 | 0.29
23 | 3 | CKN12221-1-ND | PTS526SK15SMTR2 LFS | SWITCH TACTILE SPST-NO 0.05A 12V |  | 3 | 0 | 0.13 | 0.39
24 | 3 | ATMEGA328P-AU-ND | ATMEGA328P-AU | IC MCU 8BIT 32KB FLASH 32TQFP |  | 3 | 0 | 2.66 | 7.98
25 | 3 | 296-27899-1-ND | INA219BIDR | IC CURRENT MONITOR 0.5% 8SOIC |  | 3 | 0 | 2.03 | 6.09
26 | 3 | 296-38849-1-ND | ADS1115IDGSR | IC ADC 16BIT SIGMA-DELTA 10VSSOP |  | 3 | 0 | 4.38 | 13.14
27 | 3 | 296-38874-1-ND | BQ24075RGTR | IC BATT CHG LI-ION 1CELL 16QFN |  | 3 | 0 | 2.13 | 6.39
28 | 3 | 296-12602-1-ND | LM317DCYR | IC REG LIN POS ADJ 1.5A SOT223-4 |  | 3 | 0 | 0.64 | 1.92
29 | 4 | 3155-16M20P2/49US-ND | 16M20P2/49US | CRYSTAL 16MHZ 20PF DIP |  | 4 | 0 | 0.15 | 0.60

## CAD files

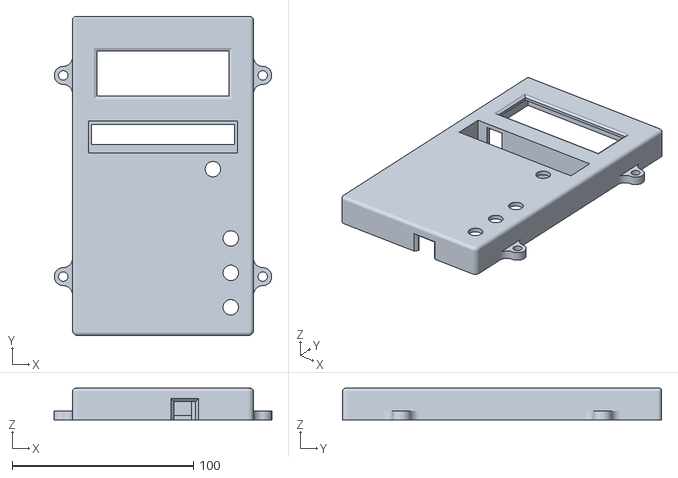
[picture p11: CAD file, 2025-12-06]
dmm/oshe_dmm_KiCAD/oshe_dmm_project_v2/V2 Primary Casing Top.stl
120.0 x 176.0 x 17.5

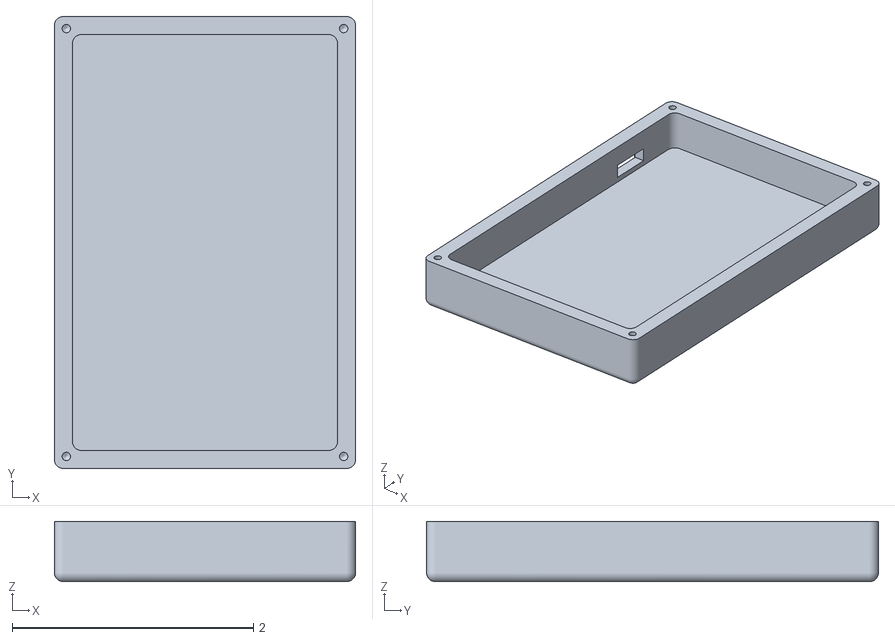
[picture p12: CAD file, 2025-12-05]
mini_dmm/mini_dmm_STLs/Mini-DMM_LowerBox.stl
2.50 x 3.75 x 0.5

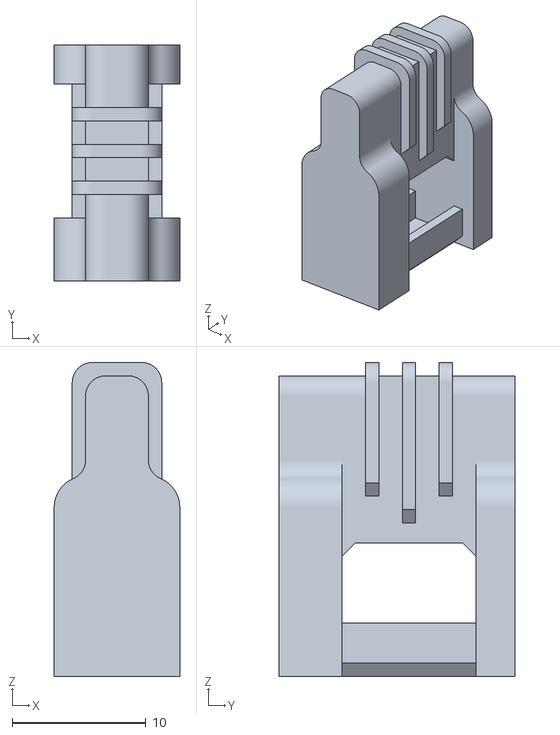
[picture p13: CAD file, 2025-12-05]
dmm/oshe_dmm_KiCAD/oshe_dmm_project_v2/V2 Slider.stl
9.40 x 17.7 x 23.5

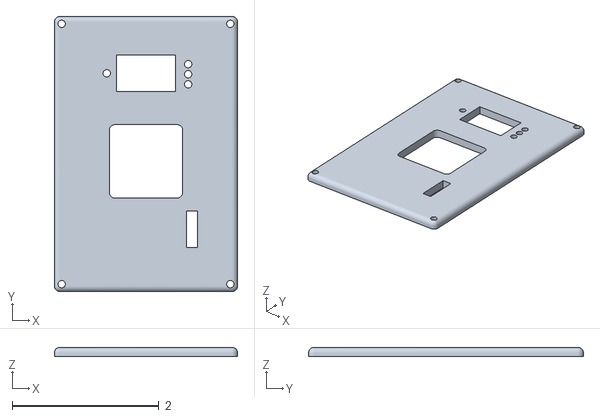
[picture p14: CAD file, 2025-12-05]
mini_dmm/mini_dmm_STLs/Mini-DMM_Lid.stl
2.50 x 3.75 x 0.125

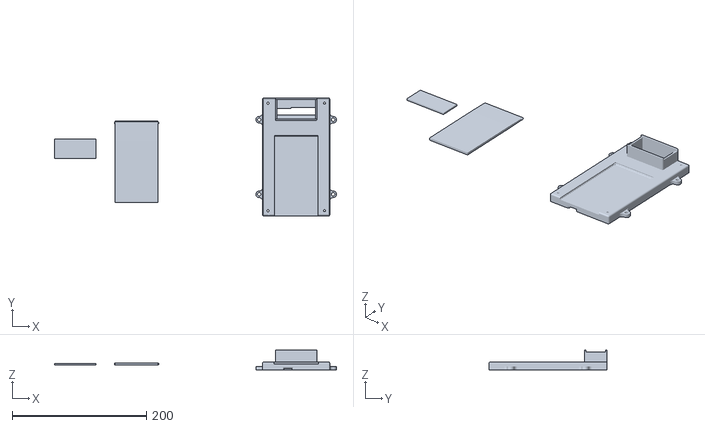
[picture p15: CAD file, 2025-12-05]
dmm/oshe_dmm_KiCAD/oshe_dmm_project_v2/V2 Primary Casing Bottom-9Volt.stl
419.8 x 176.0 x 29.5

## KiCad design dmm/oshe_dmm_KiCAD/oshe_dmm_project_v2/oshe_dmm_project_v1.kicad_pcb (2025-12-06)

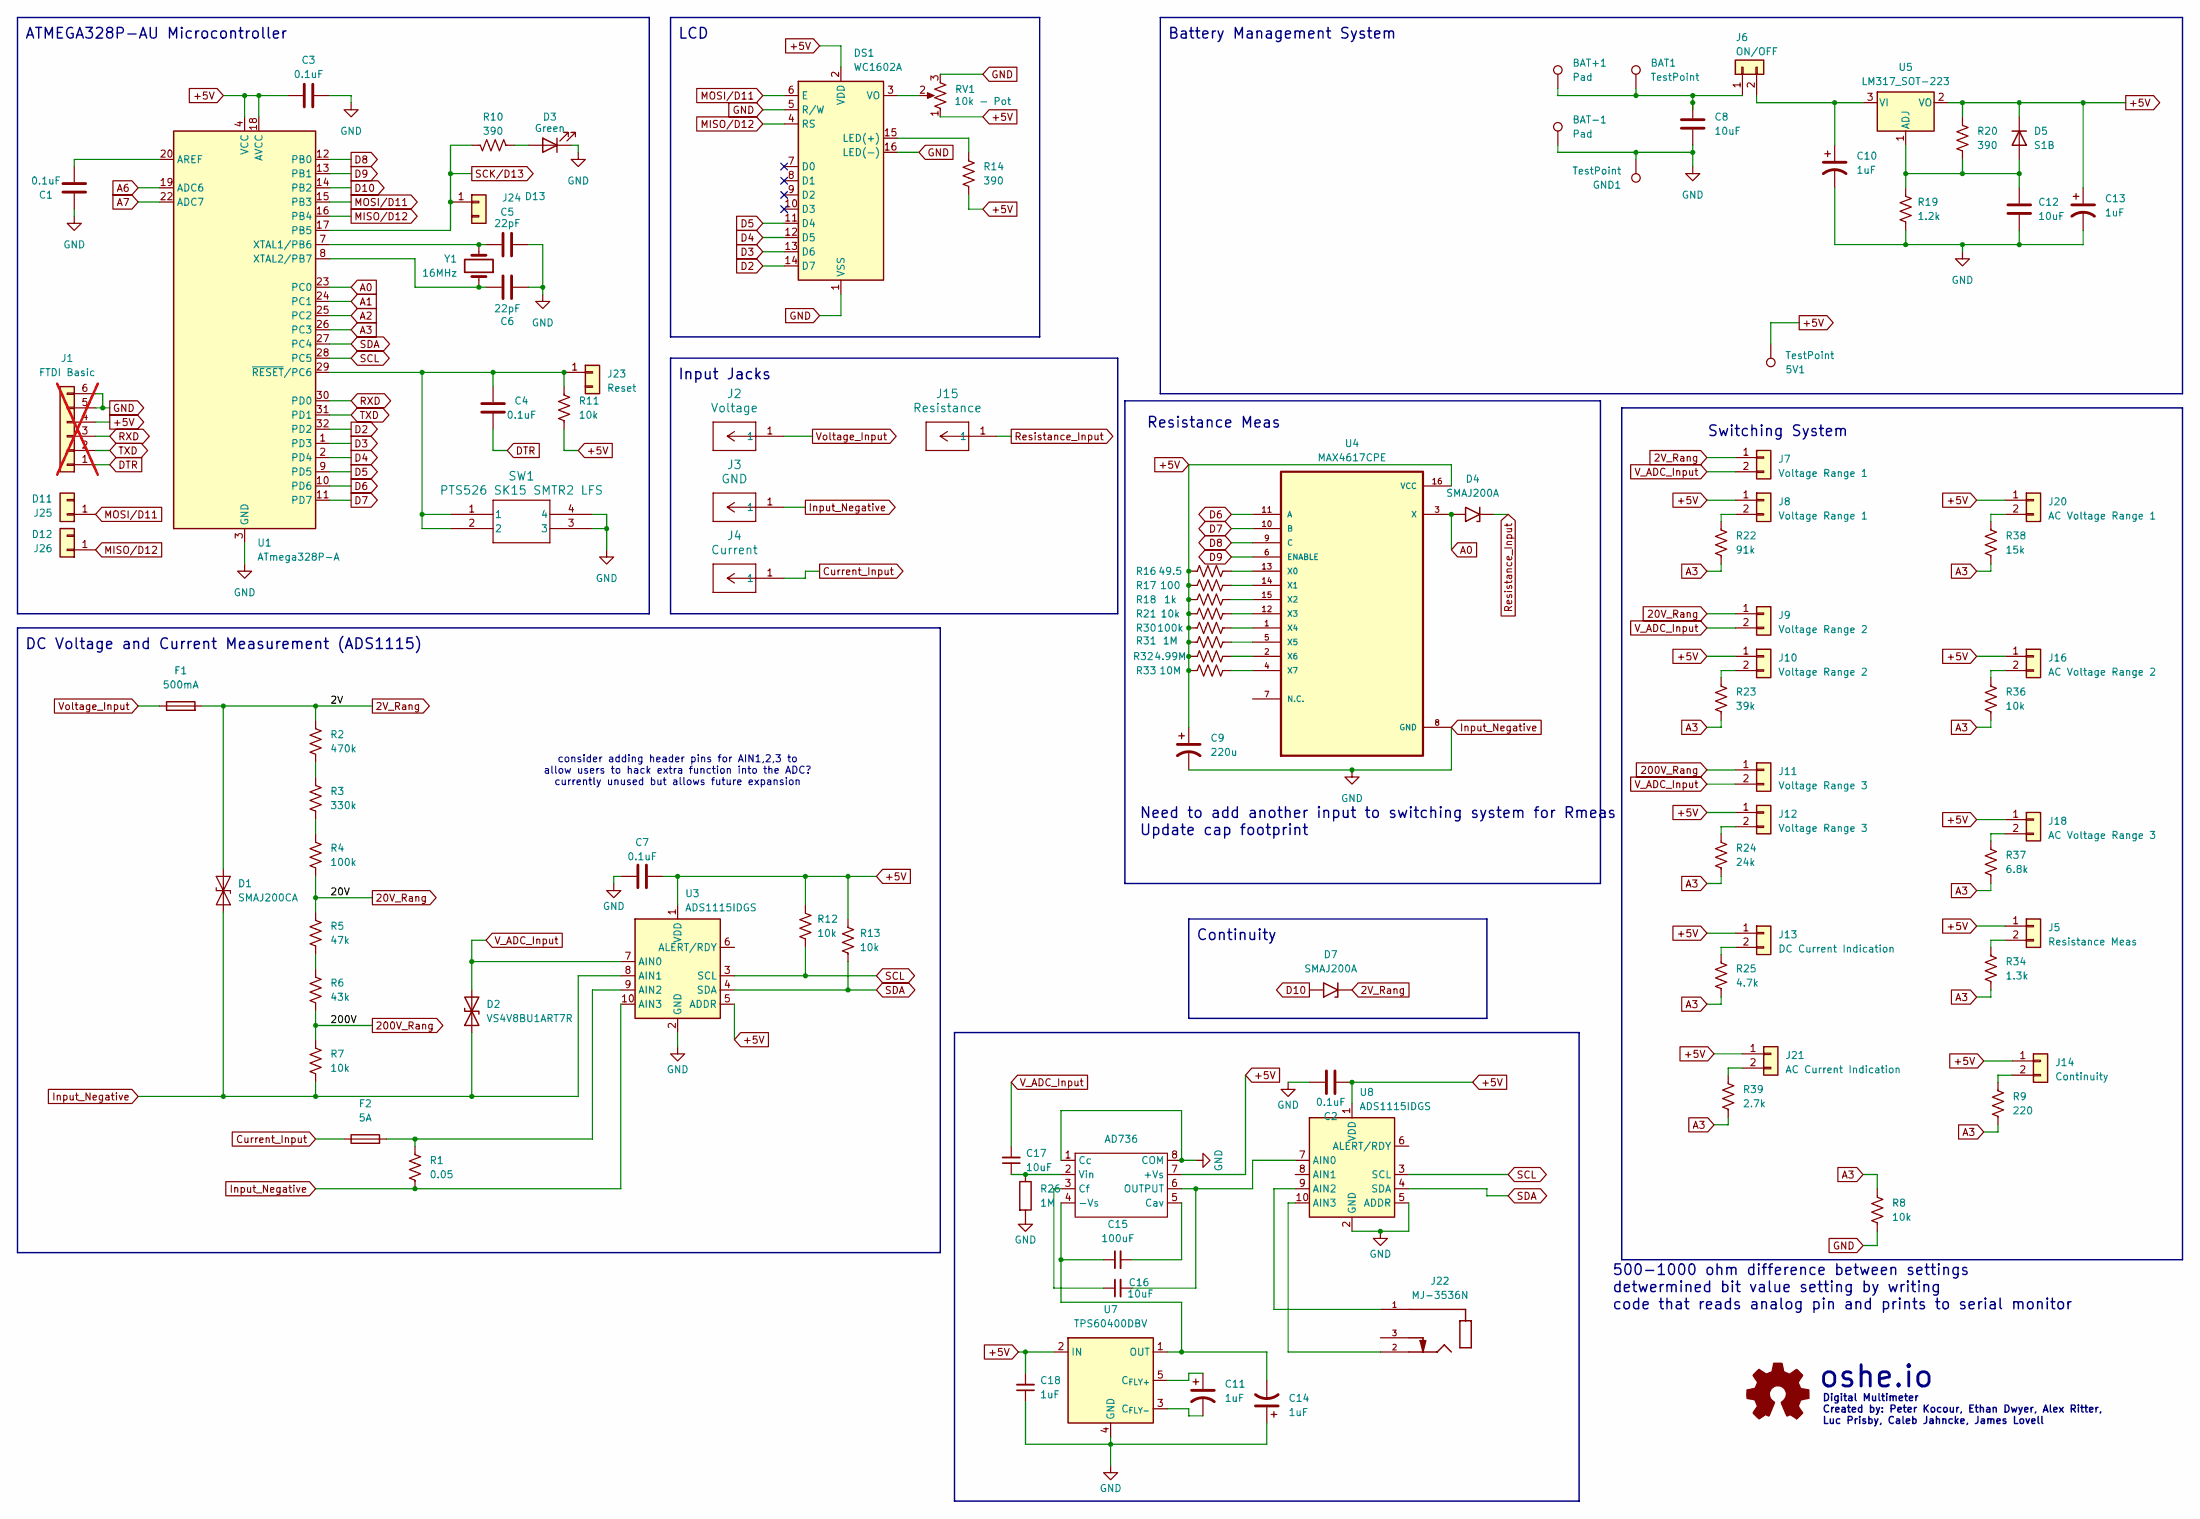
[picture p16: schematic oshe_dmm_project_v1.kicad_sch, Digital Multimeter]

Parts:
5V1: TestPoint; TestPoint_Keystone_5019_Minature
BAT1: TestPoint; TestPoint_Keystone_5019_Minature
BAT+1: Pad; TestPoint_THTPad_D4.0mm_Drill2.0mm
BAT-1: Pad; TestPoint_THTPad_D4.0mm_Drill2.0mm
C1, C2, C3, C4, C7: 0.1uF; C_1206_3216Metric_Pad1.33x1.80mm_HandSolder
C5, C6: 22pF; C_1206_3216Metric_Pad1.33x1.80mm_HandSolder
C8, C12, C16, C17: 10uF; C_1206_3216Metric_Pad1.33x1.80mm_HandSolder
C9: 220u; CP_Radial_D6.3mm_P2.50mm
C10, C11, C13, C14, C18: 1uF; CP_Elec_4x4.5
C15: 100uF; CAPC3216X190N
D1: SMAJ200CA; D_SMA
D2: VS4V8BU1ART7R; D_0805_2012Metric_Pad1.15x1.40mm_HandSolder
D3: Green; LED_1206_3216Metric_Pad1.42x1.75mm_HandSolder
D4, D7: SMAJ200A; D_SMA
D5: S1B; D_SMA
DS1: WC1602A
F1: 500mA; FUSE_4628
F2: 5A; FUSE_4628
GND1: TestPoint; TestPoint_Keystone_5019_Minature
J1: FTDI Basic; PinSocket_1x06_P2.54mm_Vertical; not fitted
J2: Voltage; CONN_575-8_KEY
J3: GND; CONN_575-8_KEY
J4: Current; CONN_575-8_KEY
J5: Resistance Meas; PinHeader_1x02_P2.54mm_Vertical
J6: ON/OFF; PinHeader_1x02_P2.54mm_Vertical
J7, J8: Voltage Range 1; PinHeader_1x02_P2.54mm_Vertical
J9, J10: Voltage Range 2; PinHeader_1x02_P2.54mm_Vertical
J11, J12: Voltage Range 3; PinHeader_1x02_P2.54mm_Vertical
J13: DC Current Indication; PinHeader_1x02_P2.54mm_Vertical
J14: Continuity; PinHeader_1x02_P2.54mm_Vertical
J15: Resistance; CONN_575-8_KEY
J16: AC Voltage Range 2; PinHeader_1x02_P2.54mm_Vertical
J18: AC Voltage Range 3; PinHeader_1x02_P2.54mm_Vertical
J20: AC Voltage Range 1; PinHeader_1x02_P2.54mm_Vertical
J21: AC Current Indication; PinHeader_1x02_P2.54mm_Vertical
J22: MJ-3536N; SAMESKY_MJ-3536N; PARTREV 1.05
J23: Reset; PinHeader_1x01_P2.54mm_Vertical
J24: D13; PinHeader_1x01_P2.54mm_Vertical
J25: D11; PinHeader_1x01_P2.54mm_Vertical
J26: D12; PinHeader_1x01_P2.54mm_Vertical
R1: 0.05; R_2512_6332Metric_Pad1.40x3.35mm_HandSolder
R2: 470k; R_1206_3216Metric_Pad1.30x1.75mm_HandSolder
R3: 330k; R_1206_3216Metric_Pad1.30x1.75mm_HandSolder
R4, R30: 100k; R_1206_3216Metric_Pad1.30x1.75mm_HandSolder
R5: 47k; R_1206_3216Metric_Pad1.30x1.75mm_HandSolder
R6: 43k; R_1206_3216Metric_Pad1.30x1.75mm_HandSolder
R7, R8, R11, R12, R13, R21, R36: 10k; R_1206_3216Metric_Pad1.30x1.75mm_HandSolder
R9: 220; R_1206_3216Metric_Pad1.30x1.75mm_HandSolder
R10, R14, R20: 390; R_1206_3216Metric_Pad1.30x1.75mm_HandSolder
R16: 49.5; R_1206_3216Metric_Pad1.30x1.75mm_HandSolder
R17: 100; R_1206_3216Metric_Pad1.30x1.75mm_HandSolder
R18: 1k; R_1206_3216Metric_Pad1.30x1.75mm_HandSolder
R19: 1.2k; R_1206_3216Metric_Pad1.30x1.75mm_HandSolder
R22: 91k; R_1206_3216Metric_Pad1.30x1.75mm_HandSolder
R23: 39k; R_1206_3216Metric_Pad1.30x1.75mm_HandSolder
R24: 24k; R_1206_3216Metric_Pad1.30x1.75mm_HandSolder
R25: 4.7k; R_1206_3216Metric_Pad1.30x1.75mm_HandSolder
R26, R31: 1M; R_1206_3216Metric_Pad1.30x1.75mm_HandSolder
R32: 4.99M; R_1206_3216Metric_Pad1.30x1.75mm_HandSolder
R33: 10M; R_1206_3216Metric_Pad1.30x1.75mm_HandSolder
R34: 1.3k; R_1206_3216Metric_Pad1.30x1.75mm_HandSolder
R37: 6.8k; R_1206_3216Metric_Pad1.30x1.75mm_HandSolder
R38: 15k; R_1206_3216Metric_Pad1.30x1.75mm_HandSolder
R39: 2.7k; R_1206_3216Metric_Pad1.30x1.75mm_HandSolder
RV1: 10k - Pot; Potentiometer_Bourns_3266Y_Vertical
SW1: PTS526 SK15 SMTR2 LFS; SMT_FS
U1: ATmega328P-A; TQFP-32_7x7mm_P0.8mm
U2: AD736; PDIP-8_N
U3, U8: ADS1115IDGS; MODULE_ZC261500
U4: MAX4617CPE
U5: LM317_SOT-223; SOT-223-3_TabPin2
U7: TPS60400DBV; SOT-23-5
Y1: 16MHz; Crystal_HC49-U_Vertical

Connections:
2V_Rang: D1.1 (A1), D7.1 (A1), F1.2, J7.1, R2.1
20V_Rang: J9.1, R4.2, R5.1
200V_Rang: J11.1, R6.2, R7.1
+5V: 5V1.1, C2.1, C3.1, C7.2, C9.1, C13.1, C18.2, D5.1 (K), DS1.2 (VDD), J1.4, J5.1, J8.1, J10.1, J12.1, J13.1, J14.1, J16.1, J18.1, J20.1, J21.1, R11.2, R12.1, R13.1, R14.1, R16.1, R17.1, R18.1, R20.1, R21.1, R30.1, R31.1, R32.1, R33.1, RV1.1, U1.4 (VCC), U1.6 (VCC), U1.18 (AVCC), U2.7 (+Vs), U3.1 (VDD), U3.5 (ADDR), U4.16 (VCC), U5.2 (VO), U7.2 (IN), U8.1 (VDD)
A0: D4.2 (A2), U1.23 (PC0), U4.3 (X)
A1: U1.24 (PC1)
A2: U1.25 (PC2)
A3: R8.2, R9.1, R22.1, R23.1, R24.1, R25.1, R34.1, R36.1, R37.1, R38.1, R39.1, U1.26 (PC3)
A6: U1.19 (ADC6)
A7: U1.22 (ADC7)
Current_Input: F2.1, J4.1
D2: DS1.14 (D7), U1.32 (PD2)
D3: DS1.13 (D6), U1.1 (PD3)
D4: DS1.12 (D5), U1.2 (PD4)
D5: DS1.11 (D4), U1.9 (PD5)
D6: U1.10 (PD6), U4.11 (A)
D7: U1.11 (PD7), U4.10 (B)
D8: U1.12 (PB0), U4.9 (C)
D9: U1.13 (PB1), U4.6 (ENABLE)
D10: D7.2 (A2), U1.14 (PB2)
DTR: C4.2, J1.1
GND: BAT-1.1, C1.1, C2.2, C3.2, C5.2, C6.1, C7.1, C8.2, C9.2, C10.2, C12.2, C13.2, C14.1, C18.1, D1.2 (A2), D2.1 (A1), D3.1 (K), DS1.1 (VSS), DS1.5 (R/W), DS1.16 (LED(-)), GND1.1, J1.5, J1.6, J3.1, R1.2, R7.2, R8.1, R19.2, R26.2, RV1.3, SW1.3, SW1.4, U1.3 (GND), U1.5 (GND), U1.21 (GND), U2.1 (Cc), U2.8 (COM), U3.2 (GND), U3.8 (AIN1), U3.10 (AIN3), U4.8 (GND), U7.4 (GND), U8.2 (GND), U8.5 (ADDR)
MISO/D12: DS1.4 (RS), J26.1, U1.16 (PB4)
MOSI/D11: DS1.6 (E), J25.1, U1.15 (PB3)
unnamed: D3.2 (A), R10.1
unnamed: C12.1, D5.2 (A), R19.1, R20.2, U5.1 (ADJ)
unnamed: DS1.15 (LED(+)), R14.2
unnamed: DS1.3 (VO), RV1.2
unnamed: J5.2, R34.2
unnamed: BAT1.1, BAT+1.1, C8.1, J6.1
unnamed: C10.1, J6.2, U5.3 (VI)
unnamed: J8.2, R22.2
unnamed: J10.2, R23.2
unnamed: J12.2, R24.2
unnamed: J13.2, R25.2
unnamed: J14.2, R9.2
unnamed: J16.2, R36.2
unnamed: J18.2, R37.2
unnamed: J20.2, R38.2
unnamed: J21.2, R39.2
unnamed: C4.1, J23.1, R11.1, SW1.1, SW1.2, U1.29 (~RESET/PC6)
unnamed: R2.2, R3.1
unnamed: R3.2, R4.1
unnamed: R5.2, R6.1
unnamed: C1.2, U1.20 (AREF)
unnamed: C5.1, U1.7 (XTAL1/PB6), Y1.2
unnamed: C6.2, U1.8 (XTAL2/PB7), Y1.1
unnamed: C14.2, C15.1, U2.4 (-Vs), U7.1 (OUT)
unnamed: C15.2, U2.5 (Cav)
unnamed: C16.1, U2.3 (Cf)
unnamed: C16.2, U2.6 (OUTPUT), U8.7 (AIN0)
unnamed: C17.1, R26.1, U2.2 (Vin)
unnamed: F2.2, R1.1, U3.9 (AIN2)
unnamed: R16.2, U4.13 (X0)
unnamed: R17.2, U4.14 (X1)
unnamed: R18.2, U4.15 (X2)
unnamed: R21.2, U4.12 (X3)
unnamed: R30.2, U4.1 (X4)
unnamed: R31.2, U4.5 (X5)
unnamed: R32.2, U4.2 (X6)
unnamed: R33.2, U4.4 (X7)
unnamed: C11.1, U7.5 (C_{FLY+})
unnamed: C11.2, U7.3 (C_{FLY-})
unnamed: J22.1, U8.9 (AIN2)
unnamed: J22.2, U8.10 (AIN3)
RXD: J1.3, U1.30 (PD0)
Resistance_Input: D4.1 (A1), J15.1
SCK/D13: J24.1, R10.2, U1.17 (PB5)
SCL: R12.2, U1.28 (PC5), U3.3 (SCL), U8.3 (SCL)
SDA: R13.2, U1.27 (PC4), U3.4 (SDA), U8.4 (SDA)
TXD: J1.2, U1.31 (PD1)
V_ADC_Input: C17.2, D2.2 (A2), J7.2, J9.2, J11.2, U3.7 (AIN0)
Voltage_Input: F1.1, J2.1

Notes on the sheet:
Digital Multimeter Created by: Peter Kocour, Ethan Dwyer, Alex Ritter, Luc Prisby, Caleb Jahncke, James Lovell
Need to add another input to switching system for Rmeas Update cap footprint
consider adding header pins for AIN1,2,3 to allow users to hack extra function into the ADC? currently unused but allows future expansion
Resistance Meas
oshe.io
Switching System
Battery Management System
DC Voltage and Current Measurement (ADS1115)
LCD
500-1000 ohm difference between settings detwermined bit value setting by writing code that reads analog pin and prints to serial monitor
Input Jacks
Continuity
ATMEGA328P-AU Microcontroller

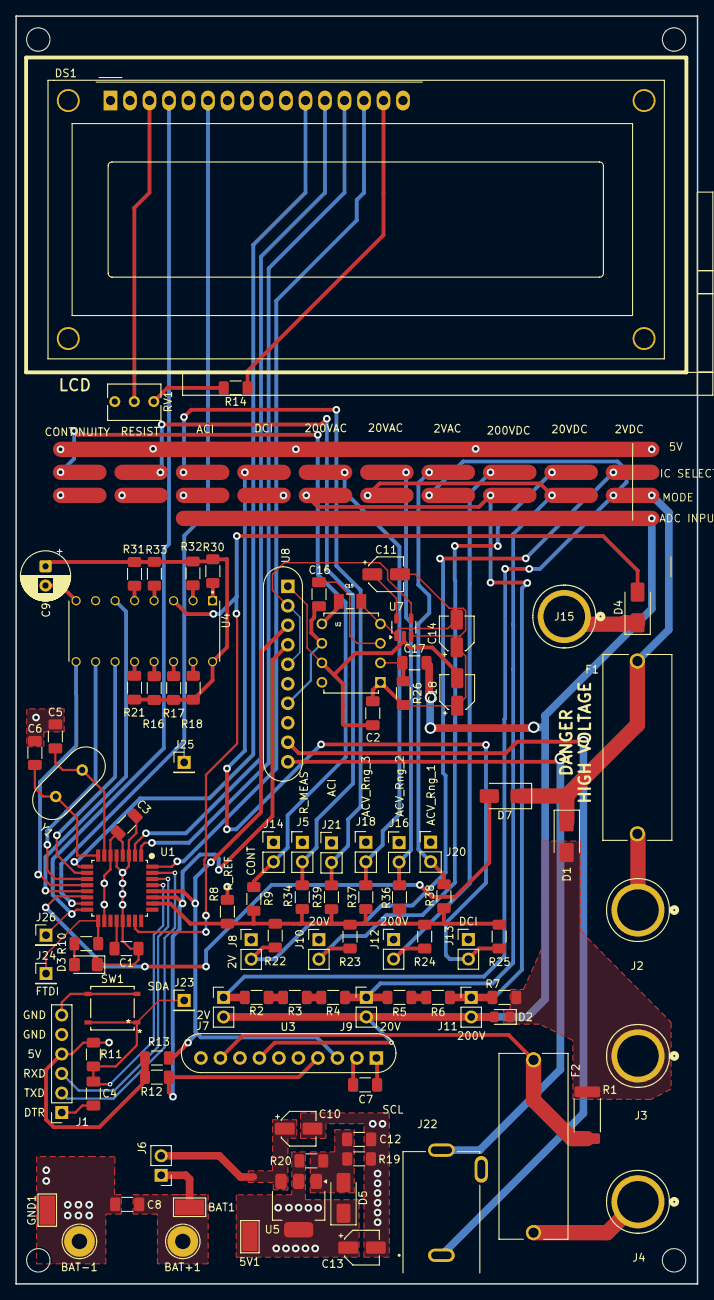
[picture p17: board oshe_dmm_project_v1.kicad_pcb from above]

Board: 4 copper layers, 88.7 x 165.1 mm, 100 parts (0 on the bottom side), 69 nets.

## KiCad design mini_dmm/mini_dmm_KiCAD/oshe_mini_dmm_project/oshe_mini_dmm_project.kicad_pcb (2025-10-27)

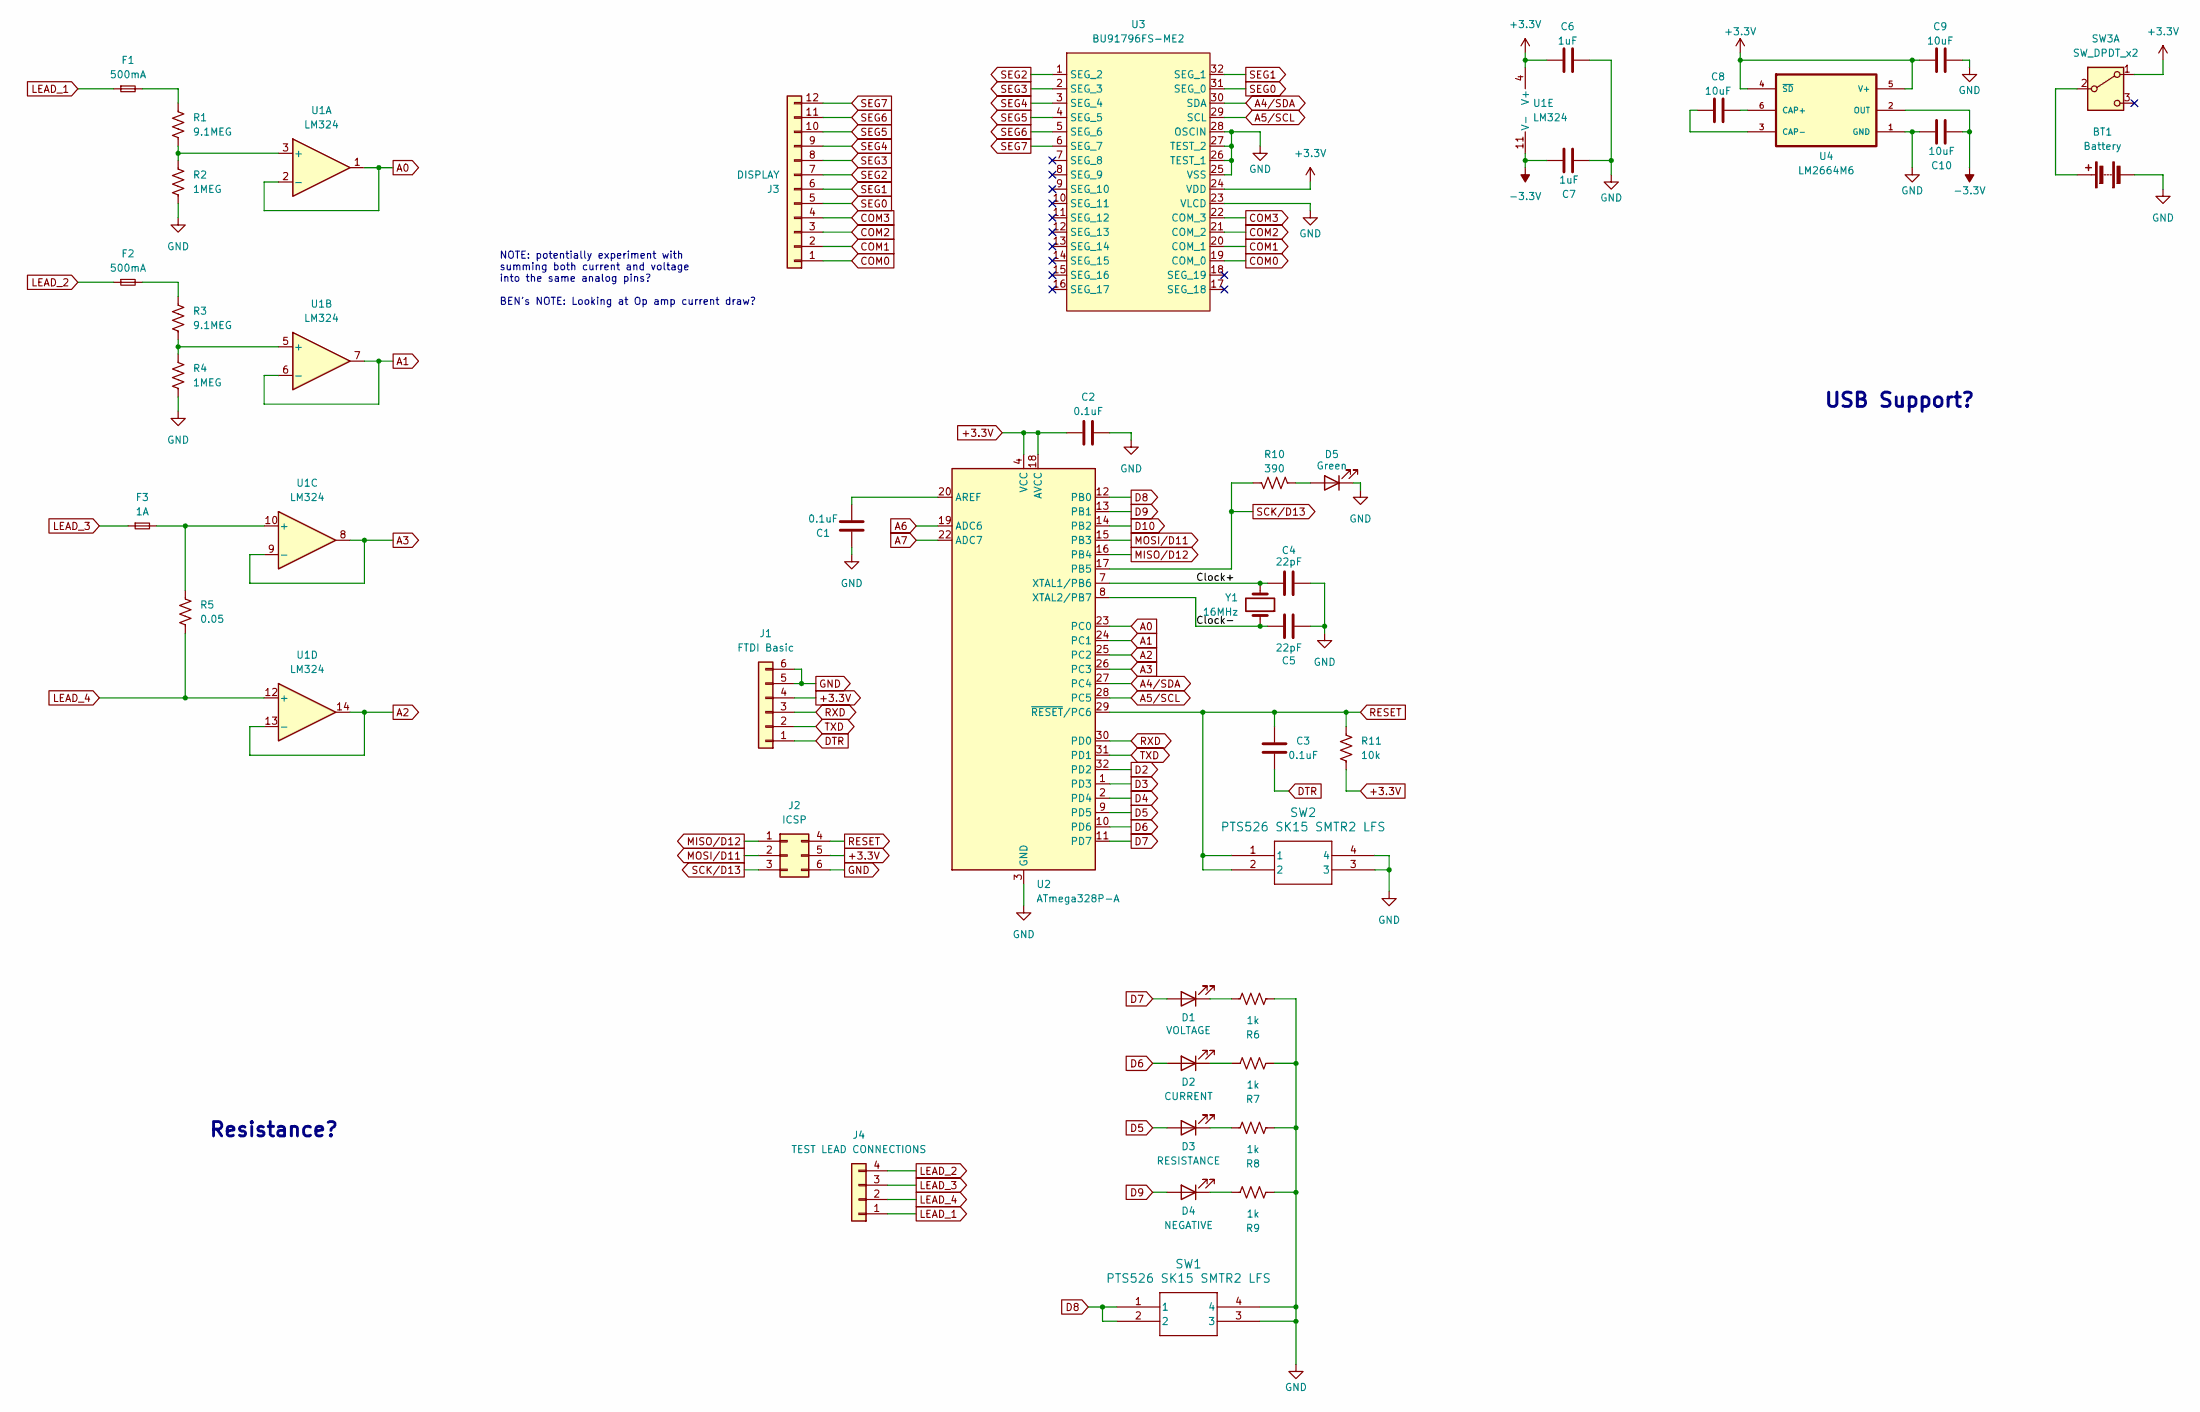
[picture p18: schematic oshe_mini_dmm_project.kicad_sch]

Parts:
BT1: Battery; BatteryHolder_Keystone_3034_1x20mm
C1, C2, C3: 0.1uF; C_0805_2012Metric_Pad1.18x1.45mm_HandSolder
C4, C5: 22pF; C_0805_2012Metric_Pad1.18x1.45mm_HandSolder
C6, C7: 1uF; C_0805_2012Metric_Pad1.18x1.45mm_HandSolder
C8, C9, C10: 10uF; C_0805_2012Metric_Pad1.18x1.45mm_HandSolder
D1: VOLTAGE; LED_0805_2012Metric_Pad1.15x1.40mm_HandSolder
D2: CURRENT; LED_0805_2012Metric_Pad1.15x1.40mm_HandSolder
D3: RESISTANCE; LED_0805_2012Metric_Pad1.15x1.40mm_HandSolder
D4: NEGATIVE; LED_0805_2012Metric_Pad1.15x1.40mm_HandSolder
D5: Green; LED_0805_2012Metric_Pad1.15x1.40mm_HandSolder
F1, F2: 500mA; Fuse_1206_3216Metric_Pad1.42x1.75mm_HandSolder
F3: 1A; Fuse_1206_3216Metric_Pad1.42x1.75mm_HandSolder
J1: FTDI Basic; PinHeader_1x06_P2.54mm_Horizontal
J2: ICSP; PinHeader_2x03_P2.54mm_Horizontal
J3: DISPLAY; LCD-S401M16KR-81359
J4: TEST LEAD CONNECTIONS; PinHeader_1x04_P2.54mm_Horizontal
R1, R3: 9.1MEG; R_0805_2012Metric_Pad1.20x1.40mm_HandSolder
R2, R4: 1MEG; R_0805_2012Metric_Pad1.20x1.40mm_HandSolder
R5: 0.05; R_2512_6332Metric_Pad1.40x3.35mm_HandSolder
R6, R7, R8, R9: 1k; R_0805_2012Metric_Pad1.20x1.40mm_HandSolder
R10: 390; R_0805_2012Metric_Pad1.20x1.40mm_HandSolder
R11: 10k; R_0805_2012Metric_Pad1.20x1.40mm_HandSolder
SW1, SW2: PTS526 SK15 SMTR2 LFS; SMT_FS
SW3: SW_DPDT_x2; SW_JS102011SAQN
U1: LM324; SOIC-14_3.9x8.7mm_P1.27mm
U2: ATmega328P-A; TQFP-32_7x7mm_P0.8mm
U3: BU91796FS-ME2; SSOP-A32
U4: LM2664M6; SOT95P280X145-6N
Y1: 16MHz; Crystal_HC49-U_Vertical

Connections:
+3.3V: C2.1, C6.2, C9.2, J1.4, J2.5, R11.2, SW3.1 (A), U1.4 (V+), U2.4 (VCC), U2.6 (VCC), U2.18 (AVCC), U3.24 (VDD), U4.4 (~SD), U4.5 (V+)
-3.3V: C7.1, C10.2, U1.11 (V-), U4.2 (OUT)
/Clock+: C4.1, U2.7 (XTAL1/PB6), Y1.2
/Clock-: C5.2, U2.8 (XTAL2/PB7), Y1.1
A0: U1.1, U1.2 (-), U2.23 (PC0)
A1: U1.6 (-), U1.7, U2.24 (PC1)
A2: U1.13 (-), U1.14, U2.25 (PC2)
A3: U1.8, U1.9 (-), U2.26 (PC3)
A4/SDA: U2.27 (PC4), U3.30 (SDA)
A5/SCL: U2.28 (PC5), U3.29 (SCL)
A6: U2.19 (ADC6)
A7: U2.22 (ADC7)
COM0: J3.1, U3.19 (COM_0)
COM1: J3.2, U3.20 (COM_1)
COM2: J3.3, U3.21 (COM_2)
COM3: J3.4, U3.22 (COM_3)
D2: U2.32 (PD2)
D3: U2.1 (PD3)
D4: U2.2 (PD4)
D5: D3.2 (A), U2.9 (PD5)
D6: D2.2 (A), U2.10 (PD6)
D7: D1.2 (A), U2.11 (PD7)
D8: SW1.1, SW1.2, U2.12 (PB0)
D9: D4.2 (A), U2.13 (PB1)
D10: U2.14 (PB2)
DTR: C3.2, J1.1
GND: BT1.2 (-), C1.1, C2.2, C4.2, C5.1, C6.1, C7.2, C9.1, C10.1, D5.1 (K), J1.5, J1.6, J2.6, R2.2, R4.2, R6.1, R7.1, R8.1, R9.1, SW1.3, SW1.4, SW2.3, SW2.4, U2.3 (GND), U2.5 (GND), U2.21 (GND), U3.23 (VLCD), U3.25 (VSS), U3.26 (TEST_1), U3.27 (TEST_2), U3.28 (OSCIN), U4.1 (GND)
LEAD_1: F1.1, J4.1
LEAD_2: F2.1, J4.4
LEAD_3: F3.1, J4.3
LEAD_4: J4.2, R5.2, U1.12 (+)
MISO/D12: J2.1, U2.16 (PB4)
MOSI/D11: J2.2, U2.15 (PB3)
unnamed: BT1.1 (+), SW3.2 (B)
unnamed: D1.1 (K), R6.2
unnamed: D2.1 (K), R7.2
unnamed: D3.1 (K), R8.2
unnamed: D4.1 (K), R9.2
unnamed: D5.2 (A), R10.1
unnamed: F1.2, R1.1
unnamed: F2.2, R3.1
unnamed: R1.2, R2.1, U1.3 (+)
unnamed: R3.2, R4.1, U1.5 (+)
unnamed: F3.2, R5.1, U1.10 (+)
unnamed: C1.2, U2.20 (AREF)
unnamed: C8.1, U4.6 (CAP+)
unnamed: C8.2, U4.3 (CAP-)
RESET: C3.1, J2.4, R11.1, SW2.1, SW2.2, U2.29 (~RESET/PC6)
RXD: J1.3, U2.30 (PD0)
SCK/D13: J2.3, R10.2, U2.17 (PB5)
SEG0: J3.5, U3.31 (SEG_0)
SEG1: J3.6, U3.32 (SEG_1)
SEG2: J3.7, U3.1 (SEG_2)
SEG3: J3.8, U3.2 (SEG_3)
SEG4: J3.9, U3.3 (SEG_4)
SEG5: J3.10, U3.4 (SEG_5)
SEG6: J3.11, U3.5 (SEG_6)
SEG7: J3.12, U3.6 (SEG_7)
TXD: J1.2, U2.31 (PD1)

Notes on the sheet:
Resistance?
NOTE: potentially experiment with summing both current and voltage into the same analog pins? BEN's NOTE: Looking at Op amp current draw?
USB Support?

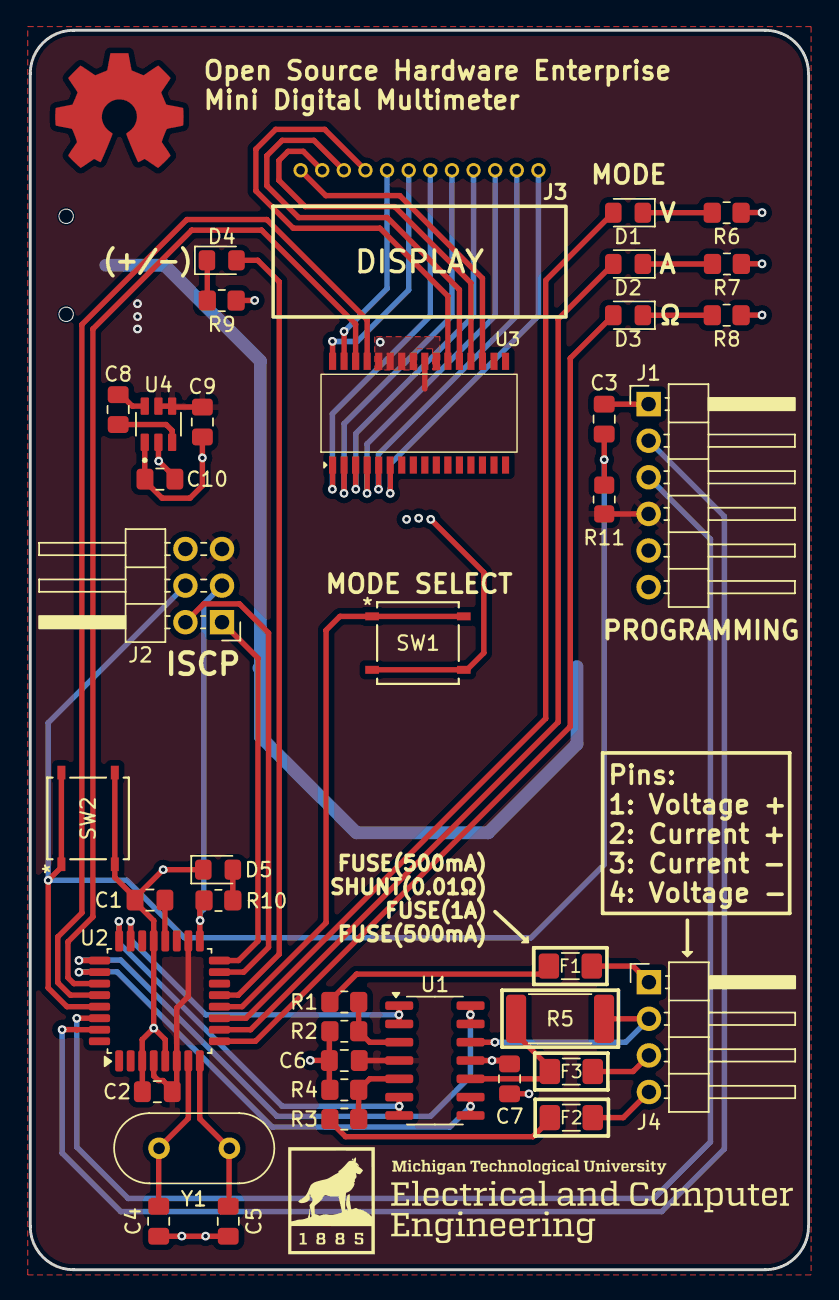
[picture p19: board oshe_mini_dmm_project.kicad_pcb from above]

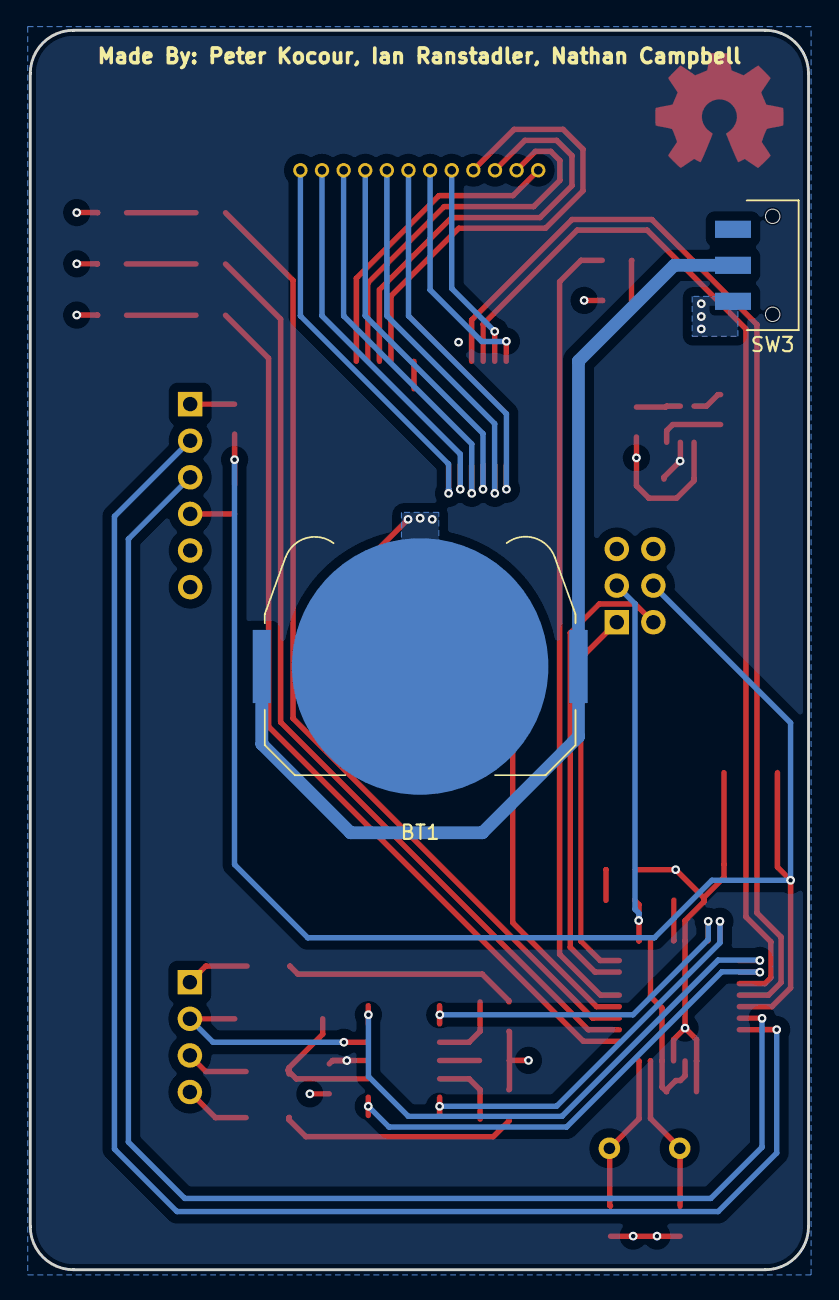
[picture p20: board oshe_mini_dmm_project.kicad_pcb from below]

Board: 4 copper layers, 54.0 x 86.0 mm, 42 parts (2 on the bottom side), 53 nets.

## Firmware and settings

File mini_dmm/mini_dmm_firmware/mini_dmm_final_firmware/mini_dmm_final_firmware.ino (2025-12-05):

#include <Wire.h>
#include <Arduino.h>

// ---------- BU91796 LCD driver (I2C) ----------

#define BU91796_I2C_ADDR 0x3E
#define DDRAM_SIZE 20

const uint8_t CMD_ICSET_SWRESET = 0xEA;
const uint8_t CMD_BLKCTL        = 0xF0;
const uint8_t CMD_DISCTL_ON     = 0xBF;
const uint8_t CMD_APCTL         = 0xFC;
const uint8_t CMD_MODESET_ON    = 0xC8;

static inline uint8_t ADSET(uint8_t addr) { return (addr & 0x7F); }

uint8_t ddram[DDRAM_SIZE];

struct SegMap { uint8_t addr; uint8_t mask; };

// Segmap taken from your provided mapping
SegMap digitSegments[4][8] = {
  { {0x0A,0x01}, {0x0A,0x02}, {0x0A,0x04}, {0x1A,0x51},
    {0x1A,0x42}, {0x1A,0x16}, {0x1A,0x20}, {0x0A,0x08} },
  { {0x0B,0x01}, {0x0B,0x02}, {0x0B,0x04}, {0x0B,0x42},
    {0x0B,0x40}, {0x0B,0x16}, {0x0B,0x20}, {0x0B,0x08} },
  { {0x0C,0x01}, {0x0C,0x02}, {0x0C,0x04}, {0x0C,0x42},
    {0x0C,0x40}, {0x0C,0x16}, {0x0C,0x20}, {0x0C,0x08} },
  { {0x0D,0x01}, {0x0D,0x02}, {0x0D,0x04}, {0x0D,0x42},
    {0x0D,0x40}, {0x0D,0x16}, {0x0D,0x20}, {0x0D,0x08} }
};

// 7-segment patterns for digits 0..9 (a..g)
const bool segPattern[10][7] = {
  {1,1,1,1,1,1,0}, {0,1,1,0,0,0,0}, {1,1,0,1,1,0,1},
  {1,1,1,1,0,0,1}, {0,1,1,0,0,1,1}, {1,0,1,1,0,1,1},
  {1,0,1,1,1,1,1}, {1,1,1,0,0,0,0}, {1,1,1,1,1,1,1},
  {1,1,1,1,0,1,1}
};

void writeCommandByte(uint8_t cmd) {
  Wire.beginTransmission(BU91796_I2C_ADDR);
  Wire.write(cmd);
  Wire.endTransmission();
  delay(1);
}

void writeDDRAM(uint8_t addr, const uint8_t *buf, size_t len) {
  Wire.beginTransmission(BU91796_I2C_ADDR);
  Wire.write(ADSET(addr));
  for (size_t i = 0; i < len; ++i) Wire.write(buf[i]);
  Wire.endTransmission();
  delay(1);
}

void bu91796_init() {
  delay(5);
  writeCommandByte(CMD_ICSET_SWRESET);
  delay(5);
  writeCommandByte(CMD_BLKCTL);
  writeCommandByte(CMD_DISCTL_ON);
  writeCommandByte(CMD_APCTL);
  writeCommandByte(CMD_MODESET_ON);
  memset(ddram, 0x00, DDRAM_SIZE);
  writeDDRAM(0x00, ddram, DDRAM_SIZE);
}

// Set or clear a mapped segment for a digit (digitIndex 0..3, segIndex 0..7 where 7 is DP)
void setSegmentLocal(int digitIndex, int segIndex, bool on) {
  if (digitIndex < 0 || digitIndex >= 4) return;
  SegMap m = digitSegments[digitIndex][segIndex];
  if (m.addr >= DDRAM_SIZE || m.mask == 0x00) return;
  if (on) ddram[m.addr] |= m.mask;
  else    ddram[m.addr] &= ~m.mask;
}

void updateDisplayFromBuffer() {
  writeDDRAM(0x00, ddram, DDRAM_SIZE);
}

// Display four characters (digits, '.' for DP, space for blank, '-' for dash)
void displayStringFour(const char *s) {
  memset(ddram, 0x00, DDRAM_SIZE);
  int digit = 0;
  for (size_t i = 0; s[i] != '\0' && digit < 4; ++i) {
    char c = s[i];
    if (c == '.') {
      if (digit > 0) setSegmentLocal(digit-1, 7, true); // DP tied to previous digit
    } else if (c >= '0' && c <= '9') {
      int val = c - '0';
      for (int si = 0; si < 7; ++si) setSegmentLocal(digit, si, segPattern[val][si]);
      digit++;
    } else if (c == ' ') {
      digit++;
    } else if (c == '-') {
      // Use segment 'd' (index 3) to approximate a minus sign
      setSegmentLocal(digit, 3, true);
      digit++;
    }
  }
  updateDisplayFromBuffer();
}

// ---------- Measurement, EMA and alpha-beta filters ----------

const int pinA0 = A0;
const int pinA1 = A1;
const int pinA2 = A2;
const int pinA3 = A3;

const int btnPin = 8;      // pushbutton, active LOW
const int ledVoltage = 7;  // indicates voltage mode (mode == 1)
const int ledCurrent = 6;  // indicates current mode (mode == 2)
const int ledNegative = 9; // indicates displayed numeric value is negative

const float shunt_resistor = 10.0f; // ohms
const float divider_ratio = 10.2f;

const float offset_magnitude_voltage = 0.0f; // volts
const float offset_magnitude_current = -0.025f; // amps

const float ADC_REF_V = 5.0f; // ADC reference
const int ADC_MAX = 1023;

int current_mode = 1; // 1 = voltage, 2 = current

// EMA
const float alpha = 0.05f;
float emaA0 = NAN;
float emaA1 = NAN;
float emaA2 = NAN;
float emaA3 = NAN;

// Debounce
unsigned long lastDebounceTime = 0;
const unsigned long debounceDelay = 50;
int lastButtonState = HIGH;
int stableButtonState = HIGH;

// alpha-beta filter state for current
const float abc_alpha = 0.6f;
const float abc_beta  = 0.2f;
float abc_est = 0.0f;
float abc_rate = 0.0f;
bool abc_initialized = false;
unsigned long abc_lastTime = 0;

// alpha-beta filter state for voltage
const float abv_alpha = 0.6f;
const float abv_beta  = 0.2f;
float abv_est = 0.0f;
float abv_rate = 0.0f;
bool abv_initialized = false;
unsigned long abv_lastTime = 0;

float rawToVoltage(int raw) {
  return (raw * ADC_REF_V) / (float)ADC_MAX;
}

float readVoltagePin(int pin) {
  int raw = analogRead(pin);
  return rawToVoltage(raw);
}

float updateEMA(float sample, float prevEMA) {
  if (isnan(prevEMA)) return sample;
  return alpha * sample + (1.0f - alpha) * prevEMA;
}

float applySignAwareOffset(float value, float offsetMagnitude) {
  if (value > 0.1f) return value + offsetMagnitude;
  if (value < -0.1f) return value - offsetMagnitude;
  return value;
}

float updateAlphaBetaGeneric(float measurement, float &est, float &rate, bool &initialized, unsigned long &lastTime, float gain_alpha, float gain_beta) {
  unsigned long now = millis();
  if (!initialized) {
    est = measurement;
    rate = 0.0f;
    initialized = true;
    lastTime = now;
    return est;
  }
  float dt = (now - lastTime) * 0.001f;
  if (dt <= 0.0f) return est;
  float pred = est + rate * dt;
  float resid = measurement - pred;
  est  = pred + gain_alpha * resid;
  rate = rate + (gain_beta * resid) / dt;
  lastTime = now;
  return est;
}

// ---------- Formatting and display of absolute XX.XX ----------

// Build and show absolute value formatted as "II.FF" (two digits before and after decimal).
// Displays leading zero by default (e.g., 3.14 -> "03.14"). To blank the leading zero, uncomment the relevant line.
void displayAbsXXdotXX(float v) {
  if (isnan(v)) v = 0.0f;
  float absVal = fabs(v);
  if (absVal > 99.995f) absVal = 99.995f; // clamp

  int totalCents = (int)roundf(absVal * 100.0f);
  int frac = totalCents % 100;
  int integer = totalCents / 100;

  char out[8];
  int tens = integer / 10;
  int units = integer % 10;
  int tenths = frac / 10;
  int hundredths = frac % 10;

  // Build 4-character string with '.' after digit2 (between digit2 and digit3)
  // Format: D1 D2 . D3 D4  -> e.g. "12.34"
  out[0] = '0' + tens;    // set to '0'..'9'; to blank leading zero, use ' ' instead of '0' when tens==0
  if (tens == 0) out[0] = ' '; // uncomment to blank leading tens
  out[1] = '0' + units;
  out[2] = '.';
  out[3] = '0' + tenths;
  out[4] = '0' + hundredths;
  out[5] = '\0';

  displayStringFour(out);
}

// ---------- Setup / Loop / UI ----------

void setup() {
  pinMode(btnPin, INPUT_PULLUP);
  pinMode(ledVoltage, OUTPUT);
  pinMode(ledCurrent, OUTPUT);
  pinMode(ledNegative, OUTPUT);

  digitalWrite(ledVoltage, LOW);
  digitalWrite(ledCurrent, LOW);
  digitalWrite(ledNegative, LOW);

  Wire.begin();
  Serial.begin(115200);
  while (!Serial) { ; }

  Serial.println("Integrated EMA + AB + BU91796 display sketch");
  bu91796_init();
  displayStringFour("00.00"); // initial display
}

void handleButton() {
  int reading = digitalRead(btnPin);
  if (reading != lastButtonState) lastDebounceTime = millis();
  if ((millis() - lastDebounceTime) > debounceDelay) {
    if (reading != stableButtonState) {
      stableButtonState = reading;
      if (stableButtonState == LOW) {
        current_mode++;
        if (current_mode > 2) current_mode = 1;
        // Reinitialize AB filter for the mode just entered
        if (current_mode == 1) {
          abv_initialized = false;
          abv_est = 0.0f;
          abv_rate = 0.0f;
          abv_lastTime = millis();
        } else if (current_mode == 2) {
          abc_initialized = false;
          abc_est = 0.0f;
          abc_rate = 0.0f;
          abc_lastTime = millis();
        }
        Serial.print("Mode changed to ");
        if (current_mode == 1) Serial.println("1 - VOLTAGE");
        else Serial.println("2 - CURRENT");
      }
    }
  }
  lastButtonState = reading;
}

void updateModeLEDs() {
  if (current_mode == 1) {
    digitalWrite(ledVoltage, HIGH);
    digitalWrite(ledCurrent, LOW);
  } else if (current_mode == 2) {
    digitalWrite(ledVoltage, LOW);
    digitalWrite(ledCurrent, HIGH);
  }
}

void loop() {
  handleButton();
  updateModeLEDs();

  // Read ADCs and update EMAs
  float v0 = readVoltagePin(pinA0);
  float v1 = readVoltagePin(pinA1);
  float v2 = readVoltagePin(pinA2);
  float v3 = readVoltagePin(pinA3);

  emaA0 = updateEMA(v0, emaA0);
  emaA1 = updateEMA(v1, emaA1);
  emaA2 = updateEMA(v2, emaA2);
  emaA3 = updateEMA(v3, emaA3);

  bool showNegative = false;

  if (current_mode == 1) {
    float vdiff = emaA0 - emaA1;
    float scaled = vdiff * divider_ratio * 2.0f;
    float measured = applySignAwareOffset(scaled, offset_magnitude_voltage);

    float abv_filtered = updateAlphaBetaGeneric(measured, abv_est, abv_rate, abv_initialized, abv_lastTime, abv_alpha, abv_beta);

    displayAbsXXdotXX(abv_filtered);
    showNegative = (abv_filtered < 0.0f);

    Serial.print("Mode1 Voltage | Vdiff(EMA)=");
    Serial.print(vdiff,6);
    Serial.print(" V | Scaled+Offset=");
    Serial.print(measured,6);
    Serial.print(" V | AB=");
    Serial.print(abv_filtered,6);
    Serial.println(" V");
  } else { // mode == 2
    float vdiff = emaA2 - emaA3;
    float raw_current = (vdiff / shunt_resistor) * 2.0f;
    float measured = applySignAwareOffset(raw_current, offset_magnitude_current);

    float abc_filtered = updateAlphaBetaGeneric(measured, abc_est, abc_rate, abc_initialized, abc_lastTime, abc_alpha, abc_beta);

    displayAbsXXdotXX(abc_filtered);
    showNegative = (abc_filtered < 0.0f);

    Serial.print("Mode2 Current | Vdiff(EMA)=");
    Serial.print(vdiff,6);
    Serial.print(" V | RawI=");
    Serial.print(raw_current,6);
    Serial.print(" A | AB=");
    Serial.print(abc_filtered,6);
    Serial.println(" A");
  }

  // Negative indicator LED for filtered value sign
  digitalWrite(ledNegative, showNegative ? HIGH : LOW);

  delay(200); // keep measurement cadence; display data is written each loop via writeDDRAM
}

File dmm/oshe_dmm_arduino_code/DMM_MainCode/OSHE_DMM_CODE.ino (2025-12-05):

/////////////////////////////////
//        DMM SOFTWARE
/////////////////////////////////
//Created By: Evan Howard
//            Luc Prisby
//            Caleb Jahncke
//            James Lovell
//Created on: 10/31/2025
//Last Modified on: 11/07/2025

//for ac current meas multiply the adc value by 5
//one adc for AC one conected to 5v adc for DC connected to GND

//voltage measure GAIN_TWO

//AC current GAIN_FOUR
//DC current GAIN_FIVE?

// Include Necessary Libraries:
#include <LiquidCrystal.h>
#include "INA219.h"
#include <Wire.h>
#include <Adafruit_ADS1X15.h>

//2 ads creation
Adafruit_ADS1115 ads1;
Adafruit_ADS1115 ads2;

// DC current Shunt Resistor
#define SHUNT_Res 0.05

// Setup for the resistance measurement
#define NUM_REF_RESISTORS 8
#define NUM_SELECT_PINS   3
#define MAX_ANALOG_VALUE  1023
#define SWITCH_RESISTANCE 4.5

// Reference Resistor values      x0    x1   x2     x3     x4       x5       x6       x7
float rRef[NUM_REF_RESISTORS] = {49.5, 100, 1000, 10000, 100000, 1000000, 4990000, 10000000};

// Multiplexer select pins              A  B  C
const byte rSelPins[NUM_SELECT_PINS] = {6, 7, 8};
const byte enableMux = 9;

//AC Current setup
const float FACTOR = 5; //5A/1V from teh CT

const float multiplier = 0.00005;

//AC voltage setup optional smoothing constants
const int numSamples = 10;    // Number of samples for moving average
float voltageAvg = 0;         // Running average
 
// Set up variables:
const int rs = 12, en = 11, d4 = 5, d5 = 4, d6 = 3, d7 = 2; // LCD Pins
const int mode_read_pin = A3;  // Pin A3 for analog input
int mode_read = 0;      // Variable to store the analog value

const int contPin = 10;


// Initialize LCD
LiquidCrystal lcd(rs, en, d4, d5, d6, d7);
// Initialize INA219 Current ADC
INA219 INA(0x40);
// Create an instance for ADS1115
Adafruit_ADS1115 ads;


void setup() 
{
  //---Set up LDC---//
  lcd.begin(16, 2);

  //---Set up INA219 Current ADC---//
  INA.setMaxCurrentShunt(5, 0.05);

  //---Set up ADS1115 Voltage ADC---//
  ads1.begin(0x48); // GND address for DC addressing
  ads2.begin(0x49); // 5v address for AC addressing

  //---Set up resistance pins---//
  pinMode(enableMux, OUTPUT);
  digitalWrite(enableMux, HIGH);      // disable all switches
  
  for (int i = 0; i < NUM_SELECT_PINS; i++)
  {
    pinMode(rSelPins[i], OUTPUT);     // Mux select pins configured as outputs
    digitalWrite(rSelPins[i], HIGH);  // select the highest Rref
  }

  delay(1000);
}

void loop() {
  // set the cursor to column 0, line 1
  // (note: line 1 is the second row, since counting begins with 0):
  lcd.setCursor(0, 1);

  // Read the analog value from pin A3
  mode_read = analogRead(mode_read_pin);
  
  // Print the value to the Serial Monitor
  //Serial.print("Analog value from A3: ");
  //Serial.println(mode_read);
  //lcd.print(mode_read);

  // Small delay for stability
  //delay(500);
  
  //---2 VOLT DC MODE---//
  if (mode_read > 60 && mode_read < 140) 
  {
    //---Pin for continuity---/
    pinMode(contPin, LOW);
    delay(100);

    ads1.setGain(GAIN_TWO);
    delay(100);

    // Force a new differential reading (AIN0 - AIN1)
    ads1.startADCReading(ADS1X15_REG_CONFIG_MUX_DIFF_0_1, false); // false means one shot mode, forces a full measurement and waits for math

    // Wait for conversion to complete
    while (!ads1.conversionComplete()) 
    {
        delay(10);
    }

    // Read ADC result
    int16_t rawValue = ads1.getLastConversionResults();
    float voltage = ads1.computeVolts(rawValue);

    // Display's Voltage Reading on LCD
    lcd.clear();
    lcd.print("OSHE DMM    (2V)");
    lcd.setCursor(0, 1);
    lcd.print("Voltage: ");
    lcd.print(voltage);
    lcd.print(" V");

    // Wait 0.5 seconds before next reading
    delay(500);
  }

  //---20 VOLT DC MODE---//
  if (mode_read > 160 && mode_read < 240) 
  {
    //---Pin for continuity---/
    pinMode(contPin, LOW);
    delay(100);

    ads1.setGain(GAIN_TWO);
    delay(100);

    // Force a new differential reading (AIN0 - AIN1)
    ads1.startADCReading(ADS1X15_REG_CONFIG_MUX_DIFF_0_1, false); // false means one shot mode, forces a full measurement and waits for math

    // Wait for conversion to complete
    while (!ads1.conversionComplete()) 
    {
        delay(10);
    }

    // Read ADC result
    int16_t rawValue = ads1.getLastConversionResults();
    float voltage = (ads1.computeVolts(rawValue) * 10.06); // * 10 puts voltage back into current range

    // Display's Voltage Reading on LCD
    lcd.clear();
    lcd.print("OSHE DMM   (20V)");
    lcd.setCursor(0, 1);
    lcd.print("Voltage: ");
    lcd.print(voltage);
    lcd.print(" V");

    // Wait 0.5 seconds before next reading
    delay(500);
  }

  //---200 VOLT DC MODE---//
  if (mode_read > 260 && mode_read < 340) 
  {
    //---Pin for continuity---/
    pinMode(contPin, LOW);
    delay(100);

    ads1.setGain(GAIN_TWO);
    delay(100);

    // Force a new differential reading (AIN0 - AIN1)
    ads1.startADCReading(ADS1X15_REG_CONFIG_MUX_DIFF_0_1, false); // false means one shot mode, forces a full measurement and waits for math

    // Wait for conversion to complete
    while (!ads1.conversionComplete()) 
    {
        delay(10);
    }

    // Read ADC result
    int16_t rawValue = ads1.getLastConversionResults();
    float voltage = (ads1.computeVolts(rawValue) * 99.06); // * 101 puts voltage back into current range

    // Display's Voltage Reading on LCD
    lcd.clear();
    lcd.print("OSHE DMM  (200V)");
    lcd.setCursor(0, 1);
    lcd.print("Voltage: ");
    lcd.print(voltage);
    lcd.print(" V");

    // Wait 0.5 seconds before next reading
    delay(500);
  }

  //---2 VOLT AC MODE---//
  if (mode_read > 360 && mode_read < 440)
  {
    //---Pin for continuity---/
    pinMode(contPin, LOW);
    delay(100);

    ads2.setGain(GAIN_TWO);
    delay(100);

    // Read single-ended channel A0 (to GND)
    int16_t raw = ads2.readADC_SingleEnded(0);
    float volts = ads2.computeVolts(raw);

    // Simple moving average for smoothing
    static float readings[numSamples];
    static int index = 0;
    static bool filled = false;

    readings[index] = volts;
    index = (index + 1) % numSamples;

    float sum = 0;
    for (int i = 0; i < (filled ? numSamples : index); i++) 
    {
      sum += readings[i];
    }
    voltageAvg = sum / (filled ? numSamples : index);
    if (index == 0) filled = true;

    // Print results
    /*Serial.print("Raw: "); Serial.print(raw);
    Serial.print("   Instant: "); Serial.print(volts, 4);
    Serial.print(" V   Smoothed: "); Serial.print(voltageAvg, 4);
    Serial.println(" V");*/

    lcd.clear();
    lcd.print("OSHE DMM  (2VAC)");
    lcd.setCursor(0, 1);
    lcd.print("Voltage: ");
    lcd.print(voltageAvg);
    lcd.print(" V");

    // Wait 0.5 seconds before next reading
    delay(500);
  }

  //---20 VOLT AC MODE---//
  if (mode_read > 460 && mode_read < 540)
  {
    //---Pin for continuity---/
    pinMode(contPin, LOW);
    delay(100);
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

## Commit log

2025-02-07 Created the kicad project files
    [oshe_dmm_project_v1.kicad_pcb, oshe_dmm_project_v1.kicad_sch]
2025-02-07 Started the primary schematic file
    [oshe_dmm_project_v1.kicad_sch]
2025-02-08 Added BMS to schematic
    [oshe_dmm_project_v1.kicad_sch]
2025-02-10 Updated main schematic
    [oshe_dmm_project_v1.kicad_sch]
2025-02-10 Created an initial PCB
    [oshe_dmm_project_v1.kicad_pcb, oshe_dmm_project_v1.kicad_sch]
2025-02-10 Made some changes to the PCB
    [oshe_dmm_project_v1.kicad_pcb, oshe_dmm_project_v1.kicad_sch]
2025-02-10 Made more PCB changes
    [oshe_dmm_project_v1.kicad_pcb, oshe_dmm_project_v1.kicad_sch]
2025-02-10 Made more changes
    [oshe_dmm_project_v1.kicad_pcb, oshe_dmm_project_v1.kicad_sch]
2025-02-12 Changed some stuff
    [Current_Measurement.kicad_sch, Input_Protection.kicad_sch, Voltage_Measurement.kicad_sch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]
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2025-02-19 Made changes to PCB and Schematic
    [Current_Measurement.kicad_sch, oshe_dmm_project_v1.kicad_pcb, oshe_dmm_project_v1.kicad_sch]
2025-02-19 Made some PCB changes
    [oshe_dmm_project_v1.kicad_pcb]
2025-02-23 Worked on the PCB
    [Current_Measurement.kicad_sch, oshe_dmm_project_v1.kicad_pcb, oshe_dmm_project_v1.kicad_sch]
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2025-02-25 Made some more PCB changes
    [oshe_dmm_project_v1.kicad_pcb, oshe_dmm_project_v1.kicad_sch]
2025-02-27 Finalized the BMS system
    [oshe_dmm_project_v1.kicad_pcb, oshe_dmm_project_v1.kicad_sch]
2025-02-28 Updated input protection schematic.
    [Input_Protection.kicad_sch]
2025-02-28 Made some PCB design changes
    [oshe_dmm_project_v1.kicad_pcb]
2025-02-28 Update Voltage_Measurement.kicad_sch
    James- copied my existing voltage circuit. This is a rough draft that contains the switch and the correct resistor values, but does NOT have the protection stuff we talked about at our last meeting. Working on that for Saturday.
    [Voltage_Measurement.kicad_sch]
2025-03-01 Made some PCB and Schematic Changes
    [Input_Protection.kicad_sch, Voltage_Measurement.kicad_sch, oshe_dmm_project_v1.kicad_pcb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]
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2025-03-01 made some more changes!
    [oshe_dmm_project_v1.kicad_pcb, oshe_dmm_project_v1.kicad_sch]
2025-03-01 Update oshe_dmm_project_v1.kicad_sch
    Updated voltage schematic.
    [oshe_dmm_project_v1.kicad_sch]
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2025-03-03 updated voltage circuit.
    Allows negative voltage measurement
    [oshe_dmm_project_v1.kicad_sch]
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2025-03-05 More changes plus custom footprints and symbols!
    [oshe_dmm_project_v1.kicad_pcb, oshe_dmm_project_v1.kicad_sch]
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2025-03-09 Replaced PCB file with update
    [oshe_dmm_project_v1.kicad_pcb]
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2025-03-10 Trying to fit everything on the board
    [oshe_dmm_project_v1.kicad_pcb, oshe_dmm_project_v1.kicad_sch]
2025-03-11 Swapped Miso/Mosi Pins
    [oshe_dmm_project_v1.kicad_sch]
2025-03-11 PCB is almost done!
    [oshe_dmm_project_v1.kicad_pcb, oshe_dmm_project_v1.kicad_sch]
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2025-03-12 Updated V1 Board Revision
    [oshe_dmm_project_v1.kicad_pcb]
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2025-03-14 Final Board complete + BOM
    Final board design is complete and ready to order. Bill of Materials has also been completed.
    [DMM_Digikey_Cart_03-13-2025.xlsx, oshe_dmm_project_v1.kicad_pcb, oshe_dmm_project_v1.kicad_sch]
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2025-03-30 Created test circuit schematic and uploaded code to folder
    [dmm_test_circuit.kicad_sch, oshe_dmm_project_v1.kicad_sch]
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2025-09-04 Moved some folders around
    [DMM_Digikey_Cart_03-13-2025.xlsx, dmm_test_circuit.kicad_sch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]
2025-09-04 Created the KiCAD project
    [oshe_mini_dmm_project.kicad_pcb, oshe_mini_dmm_project.kicad_sch]
2025-09-04 Created new kicad project for dmm
    [oshe_dmm_project_v2.kicad_pcb, oshe_dmm_project_v2.kicad_sch]
2025-09-04 Revert "Delete DMM directory"
    This reverts commit 6c336f6cfc18ae221bbbf7f589b9bed94631240a.
    [DMM_Digikey_Cart_03-13-2025.xlsx, dmm_test_circuit.kicad_sch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]
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2025-09-04 Fixed the location of files
    [DMM_Digikey_Cart_03-13-2025.xlsx, dmm_test_circuit.kicad_sch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]
2025-09-04 Moved some stuff around
    [oshe_mini_dmm_project.kicad_pcb, oshe_mini_dmm_project.kicad_sch]
2025-09-18 added to mini dmm schematic
    [oshe_mini_dmm_project.kicad_sch]
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2025-10-05 Made some more updates!
    [oshe_mini_dmm_project.kicad_pcb, oshe_mini_dmm_project.kicad_sch]
2025-10-06 created horizontal switching rail in V2 folder. copied V1 files
    [dmm_test_circuit.kicad_sch, oshe_dmm_project_v1.kicad_pcb, oshe_dmm_project_v1.kicad_sch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]
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2025-10-08 Made some more changes
    [oshe_mini_dmm_project.kicad_pcb, oshe_mini_dmm_project.kicad_sch]
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2025-10-19 schematic of res meas
    [oshe_dmm_project_v1.kicad_sch]
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2025-10-22 Add res to pcb
    [oshe_dmm_project_v1.kicad_pcb, oshe_dmm_project_v1.kicad_sch]
2025-10-24 Resistance meas on PCB, need to add lead connections
    [oshe_dmm_project_v1.kicad_pcb]
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2025-10-25 Moved DC current measurement
    Moved DC current measurement to use the same ADC as DC voltage measurement.
    [oshe_dmm_project_v1.kicad_sch]
2025-10-26 DC Voltage and Current Update
    The PCB was updated so that only one ADC is used for DC voltage and current measurement. The footprint for the ADC was also updated.
    [oshe_dmm_project_v1.kicad_pcb, oshe_dmm_project_v1.kicad_sch]
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2025-10-26 Cleaned up holes from deleted vias
    [oshe_dmm_project_v1.kicad_pcb]
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2025-10-28 AC current and voltage measurement
    Updated Schematic and PCB to include AC voltage and current measurement. Also fixed an issue with DC voltage and current ADC had the wrong pin numbers assigned.
    [oshe_dmm_project_v1.kicad_pcb, oshe_dmm_project_v1.kicad_sch]
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2025-10-28 ughhhhh i need sleep
    [oshe_dmm_project_v1.kicad_pcb]
2025-10-28 Fixed footprint errors
    [oshe_dmm_project_v1.kicad_pcb, oshe_dmm_project_v1.kicad_sch]
2025-10-28 Fixed silkscreen errors
    [oshe_dmm_project_v1.kicad_pcb]
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2025-10-29 Exported new Gerber files.
    [oshe_dmm_project_v1-B_Cu.gbr, oshe_dmm_project_v1-B_Mask.gbr, oshe_dmm_project_v1-B_Paste.gbr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]
2025-10-29 Fabricated board with JLC plugin
    [bom.csv, designators.csv, positions.csv]
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2025-10-31 Removed a via
    Removed a via that was incorrectly attached to multiple layers.
    [oshe_dmm_project_v1.kicad_pcb]
2025-11-03 Revert "Merge branch 'main' of https://github.com/peterk-mtu/oshe-dmm"
    This reverts commit ce5d962f54be2277657b6d8c67a3a7c391f0a935, reversing
    changes made to f95ec51989ec9ec0648d62f0b87f0342297760cd.
    [oshe_mini_dmm_project.kicad_sch]
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2025-11-11 Last minute changes
    Added header pins to make boot loading easier, removed battery management circuit for the rechargeable version, fixed i2c address pin that was connected to GND instead of 5V.
    [oshe_dmm_project_v1.kicad_pcb, oshe_dmm_project_v1.kicad_sch]
2025-12-04 Added New Input Probe
    Added a new input probe for resistance measurement. Also fixed the direction of some polarized capacitors.
    [oshe_dmm_project_v1.kicad_pcb, oshe_dmm_project_v1.kicad_sch]
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2025-12-05 Updated files to latest
    [oshe_mini_dmm_project.kicad_sch]
